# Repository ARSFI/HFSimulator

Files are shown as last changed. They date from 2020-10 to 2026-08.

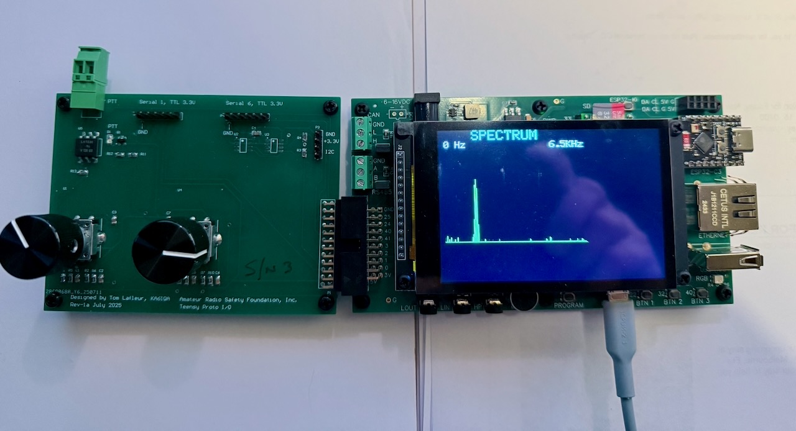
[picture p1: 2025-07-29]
hardware/Alternate hardware platforms/photos/IMG_5685.jpeg

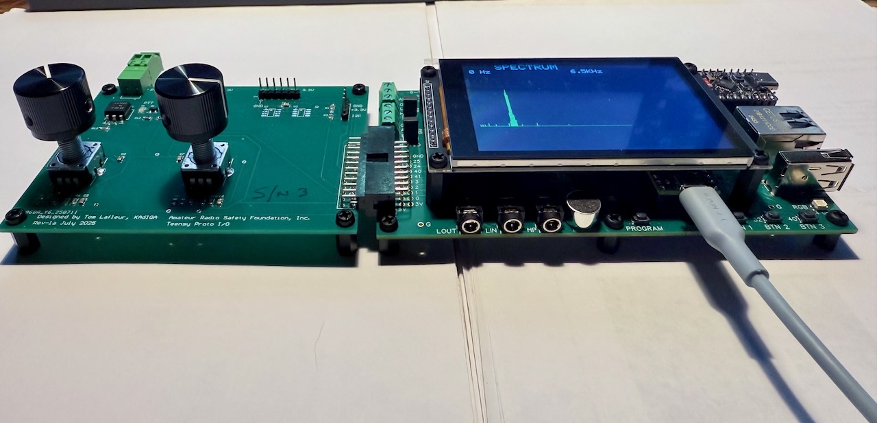
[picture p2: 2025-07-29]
hardware/Alternate hardware platforms/photos/IMG_5684.jpeg

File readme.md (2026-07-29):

<h2> A practical Open Source Ionospheric Channel Simulator</h2>                      

Rick Muething KN6KB, Tom Lafleur KA6IQA, Tom Whiteside N5TW

This project introduces a practical high-performance stand-alone and OS independent Ionospheric Channel
Simulator. Full open source documentation is available here.

A feature article with more detail is in the QEX March/April 2022.

The Amateur Radio Safety Foundation introduces the IONOS Channel Simulator, an audio-processing, 1-4 path (ray) simulator that models common HF and VHF/UHF propagation channels. It is intended to accelerate modem and protocol design, analysis, optimization and comparison, but has other uses as well. It allows off-air laboratory testing and evaluation of radio protocols and modems using statistically-standardized channel characteristics that would be almost impossible to achieve with over-the-air RF testing. Automation features allow scripting for multiple test runs under automatic control for huge time and labor savings. Since no transceivers are needed, the device may also be used as an inexpensive operator training station for exercising and teaching digital mode software. The simulator is based on the well-documented Watterson model [1] used by many laboratory grade instruments costing many thousands of dollars.

What is An Ionospheric Simulator?

Every ham learns that much of our communication relies heavily on radio wave propagation through the Ionosphere
layer. This layer reflects radio waves and can create single or multiple hop paths from station to station. While most
radio waves involve this type of propagation it is not trivial to model the constantly changing Ionosphere to test and
optimize the performance of our radios and protocols. On-air tests are notoriously unpredictable and difficult or
impossible to duplicate at another time.

In 1970 a landmark paper by Watterson, Juroshek, and Bensema was presented in the IEEE Transaction on
Communication Technology. They described a mathematical process (model) that could fairly accurately model and
simulate radio propagation over narrow band HF. This and follow-on papers by others and the CCIR/ITU defined a
set of standardized “representative test channels” that would allow computer software or hardware simulators to
statistically model HF radio propagation by manipulating the modulating audio. This has been used over the years to
develop, test, and improve many of the various digital and digital voice protocol we use today.

<h3> NOTE: Ver 2 and Ver 3 boards are identical, except that Ver 3 allows for socket pins for both Teensy 4.0 and 4.1. 
A Teensy 4.1 can be added to Ver 2 boards, but the extra pins are not in a socket. </h3>

<em><strong>Featured in the March/April 2022 issue of ARRL's QEX Magazine.

For alternate hardware update see:  

https://github.com/ARSFI/HFSimulator/tree/master/New%20alternate%20hardware%20platforms

A new small batch of IONOS development boards with a case are available from The Amateur Radio Safety Foundation, Due to the uncertainty regarding import tariffs and component costs, the final pricing for this batch has increased.

To buy assembled IONOS, blank PCB boards and cases, visit us at: https://shop.arsfi.org </a></strong></em>

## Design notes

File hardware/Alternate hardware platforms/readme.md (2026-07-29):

An alternative platform for users of this software..

Proto-supply has a development board using the Teensy 4.1, a 320x480 TFT display, with a SGTL5000 Codex.
https://protosupplies.com/product/mini-platform-teensy41/

All that is needed to run the IONOS code is a pair of encoders!,
just wire them to their I/O connector, 7 wires.
https://protosupplies.com/product/dual-rotary-encoder-module/

There is NO Audio buffering on the mini-platform, so audio in-out is connected directly to the SGTL5000 codex.

Or, we did an "encoder proto board" for another project that plugs directly into the mini-platform. 
As a minimum, you need only to install the two encoders, the 24 pin I/O connector and four jumpers.
The cost was less than $8 for 5 boards plus shipping from:
https://jlcpcb.com/

We have a version of code that runs on the board, with modification for the new TFT display.

Design documents for the "encoder proto board", including schematics, and Gerber files are available on this site.
Source code and binary HEX files for the updated TFT display are also available.

To use this board for IONOS, as a minimum, just install the two encoders, P1 and replace R5,R6,R9,R10 with jumpers.
Nothing else is needed...

If you build code from source, you will need Teensyduino version 1.60b4 or newer to support the ST7789 TFT display.

A .hex file is available to directly load into the Teensy.

https://github.com/ARSFI/HFSimulator/tree/master/New%20alternate%20hardware%20platforms/src/build/teensy.avr.teensy41

https://forum.pjrc.com/index.php?forums/announcements.6/

tom@lafleur.us ka6iqa

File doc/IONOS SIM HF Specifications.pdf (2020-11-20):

### IONOS SIM HF/VHF Channel Simulator Specifications

Rev Nov 17, 2020 (Firmware rev 2.03)

Description: IONOS SIM is a self-contained audio DSP based ionospheric simulator based on the Watterson Model [1] for ITU/CCIR standardized HF and VHF propagation paths. It uses the Teensy 4.0 CPU (ARM Cortex-M7 processor at 600 MHz) and Teensy Audio DSP Library.

Primary Use: The development, characterization, maintenance and comparison of HF and VHF modems and protocols including “sound card” protocols.

Channels Modeled: WGN (White Gaussian Noise: Spread 0 Hz, Delay: 0 ms); , MPG (CCIR Multipath Good) Spread .1 Hz, Delay .5 ms ; MPM (CCIR Multipath Moderate) Spread .5 Hz, Delay 1 ms; , MPP (CCIR Multipath Poor) Spread 1 Hz, Delay 2 ms; MPD (Multipath disturbed) Spread 2 Hz, Delay 4 ms; Flat Fading 0-40 dB, Fade Rate: .1-20 Hz; Fixed Freq offset +/- 200 Hz, 10 Hz steps; Slow FM deviation +/- 1-200 Hz, Rate .1 to 20 Hz; Multipath update rate 64x Doppler spread. Fade, offset, and FM can be combined with mode WGN.

Audio Paths: WGN: 1 path. Multipath: 2 or 4 I&Q paths. Input to Output Delay: Min 3.5ms (WGN); Max 8 ms (Multipath Disturbed). Multipath 2 paths: I2, Q2 Paths delayed by .5, 1, 2, or 4 ms.
Multipath 4 paths: 12,Q2 Paths delay by .25, .5, 1, or 2 ms I3,Q3 paths delayed by .5, 1, 2, or 4 ms.
I4,Q4 paths delayed by .75, .1.5, 3, or 6 ms

Connections Modeled: 1 Simulator: Half duplex, both sides, symmetric channel models. 2 Simulators: Full Duplex both sides: symmetric or asymmetric channel models.

Bandwidths: 3 KHz: 300 Hz to 3.3 KHz, 6 KHz: 300 Hz to 6.3 KHz. +/- 1dB Sampling rate: 44.1 KHz

Noise modeling: WGN filtered to 3 KHz or 6 KHz bandwidth. S:N -40 to +40 dB, 1 dB steps.

Inputs: Ch1, Ch2 via standard Stereo 1/8” (3.5 mm) jack. AC coupled. Input protection. Impedance > 50KOhms. Nominal input range: 10 – 1800 mv p-p. Manual input level control. Internal simulator level and input crest factor (CF) displayed.

Outputs: Ch1, Ch2 via standard Stereo 1/8” (3.5 mm) jack. AC Coupled. Short circuit protection. Impedance 150 Ohms. Nominal output range 10 - 1800 mv p-p. Manual output level control.

Power Required: Nominal 5 v (internally reg. to 3.3 V) via micro USB connector. < 200 ma.

Display: 320H x 240V pixel color TFT for Text and Graphics. (parameter settings, input level/CF, 3 & 6 KHz Spectrum Display)

Modes: Self-Test and Calibration verification to +/-1 dB Across operating BW; Setup modes and parameters;

User Parameter settings and control: Two Incremental encoders (Mode, Parameter) each with push toggle. Alternate USB serial ASCII commands for automated operation (4800-115200 baud).

Size: 6.1” (155 mm) L x 4.7” (120 mm) W x 1.4” (36 mm) H (excluding knobs).

Alternate Functions: Integrated Busy Channel Detector (experimental). Uses only serial USB ASCII command interface with host program.

[1] Watterson, C.C., J.R. Juroshek, & W.D. Bensema. 1970 Experimental confirmation of an HF channel model IEEE Transaction of Communication. Technology. Vol COM-18. Pp 792-803 Dec 1970

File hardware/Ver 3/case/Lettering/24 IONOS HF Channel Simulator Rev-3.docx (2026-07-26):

This is the text for the top and back panel…

Layout and fonts as in the photos is an example, and not firm. We hope your designer can use his/her design skills and provide suggestion of a cleaner layout. (number in from of text is font size, and is not firm)

22 IONOS HF/VHF Channel Simulator

Font is: Baskerville

12 Line-In Line-Out USB PTT

12 Rick Muething, KN6KB

12 Tom Lafleur, KA6IQA

12 Tom Whiteside, N5TW

12 Amateur Radio Safety Foundation Inc.

12 Mode Parameters

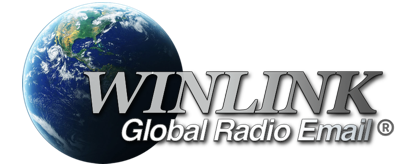
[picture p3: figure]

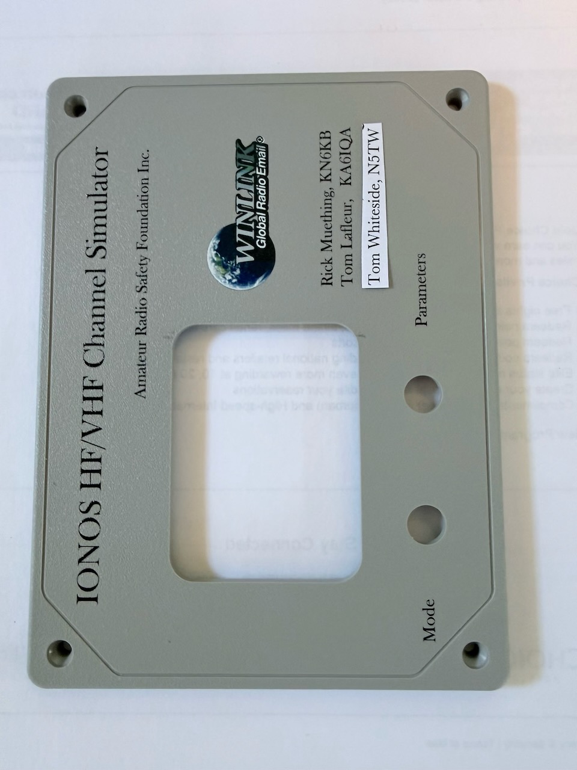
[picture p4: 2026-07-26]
hardware/Ver 3/case/Photo's/Updated Lid Artwork.jpeg

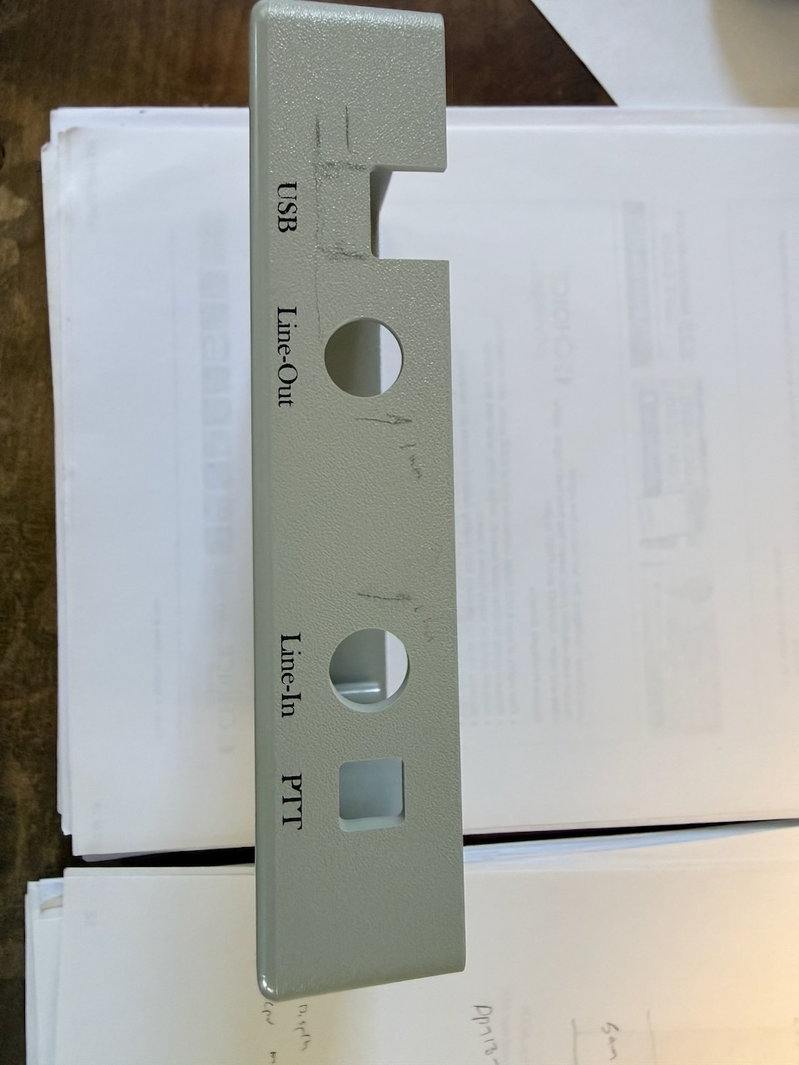
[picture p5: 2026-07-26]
hardware/Ver 3/case/PolyCase Ver-3/HF-Sim PolyCase V3/Rev-3/Photo's/Original Side Artwork.jpeg

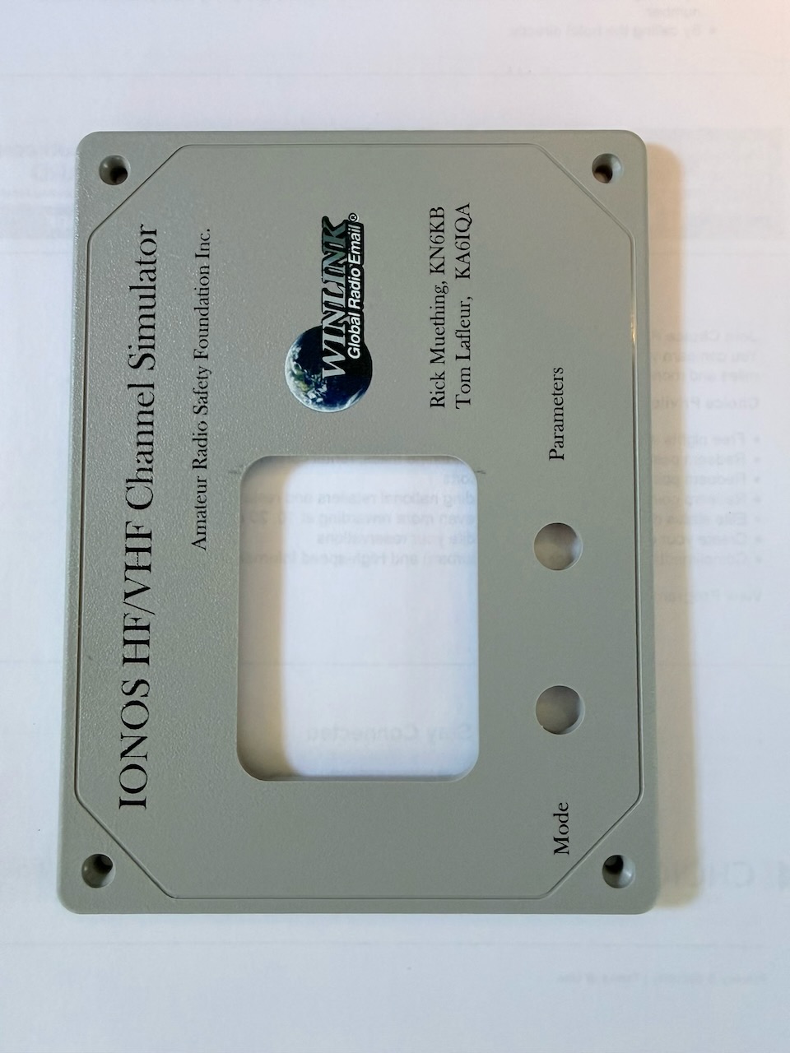
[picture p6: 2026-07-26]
hardware/Ver 3/case/Photo's/Original Lid Artwork.jpeg

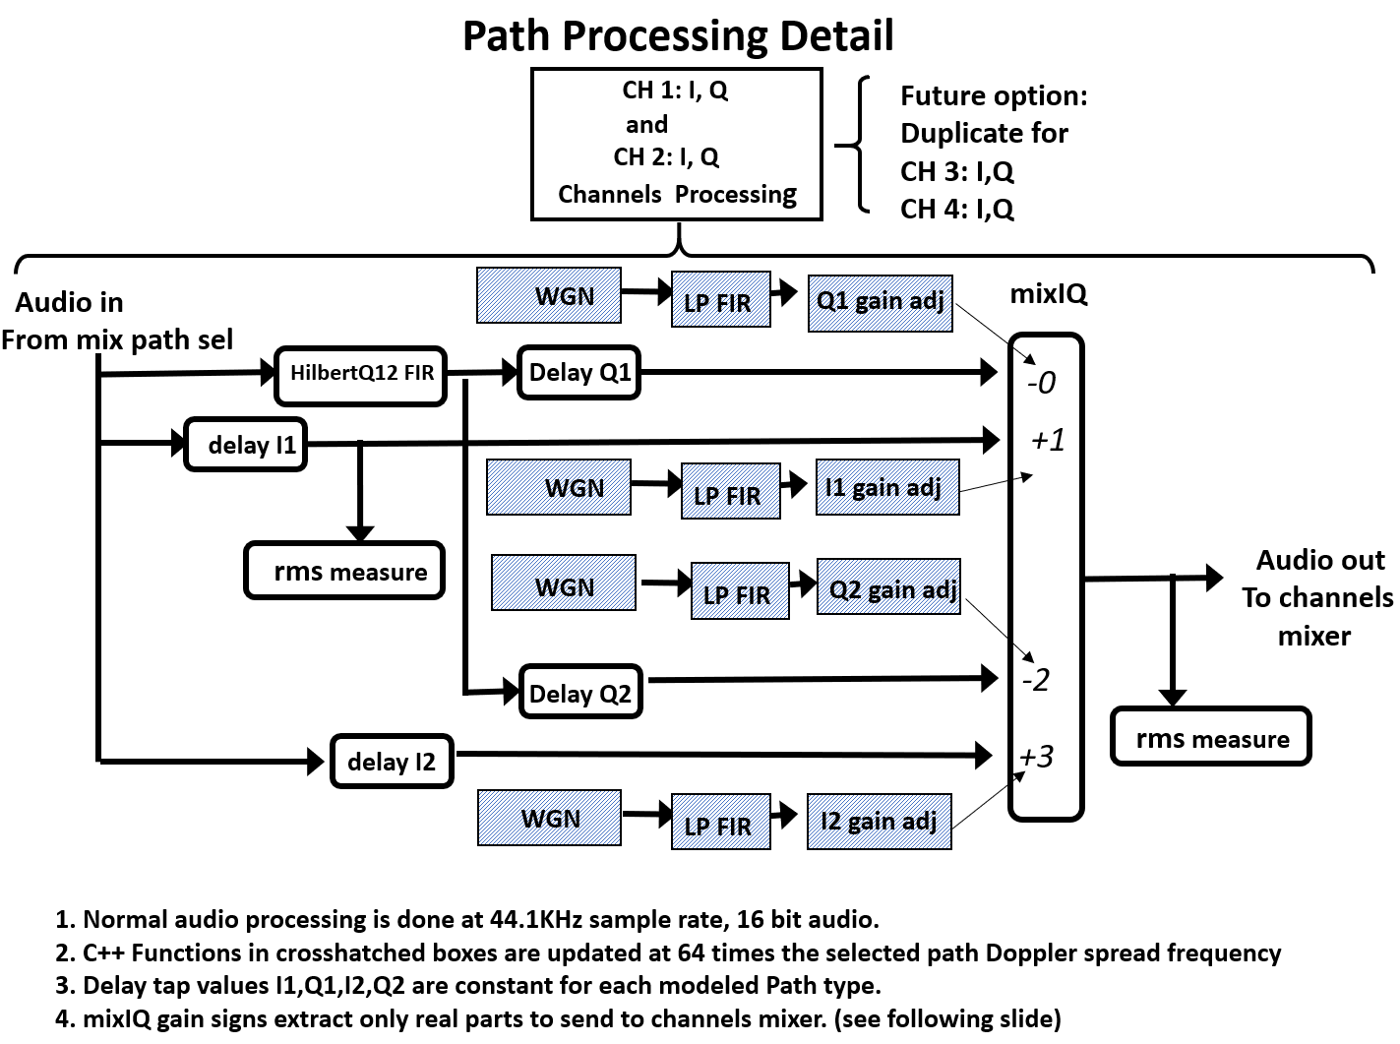
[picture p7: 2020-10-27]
doc/QEX/attachments/Fig 2. Path Processing Detail for two I & Q paths.png

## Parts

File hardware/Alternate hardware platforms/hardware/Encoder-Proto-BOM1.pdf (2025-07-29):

Designator | Comment | Part Number | Footprint | Qty | Cost | Total
C1, C2, C3,C5, C6, C7 | .01 uf/50v | | 0805 | 6 | $0.10 | $0.60
C4 | .1uf/50v | | 0805 | 1 | $0.10 | $0.10
R1,R2,R7,R8 | 4.7k | | 0805 | 4 | $0.10 | $0.40
R5,R6,R9,R10,R12 | 10k | | 0805 | 5 | $0.10 | $0.50
R3,R4 | 2.2k | | 0805 | 2 | $0.10 | $0.20
U1,U2 | Encoder | PEC11R-4225F-S0024 | | 2 | $1.78 | $3.56
R11 | 560 | | 0805 | 1 | $0.10 | $0.10
R13 | 22 Ohm | | 0805 | 1 | $0.10 | $0.10
D1 | LED Amber | LTST-C170KSKT | 0805 | 1 | $0.18 | $0.18
Q1 | FET | 2N7000BLK | SOT3 | 1 | $0.50 | $0.50
U5 | SS Switch | LH1500aab | | 1 | $2.29 | $2.29
P1 | 24 pin header | PPPC122LJBN-RC | | 1 | $1.32 | $1.32
P2,P3 | Header .1in 6 pin | | | 2 | $0.15 | $0.30
J1 | 2 Pin Jack, 5.08 | 2MA-02 | | 1 | $1.25 | $1.25
Knob | | | | 2 | $0.50 | $1.00
| | | | | | $0.00
| | | | | | $0.00
Total: | $12.40

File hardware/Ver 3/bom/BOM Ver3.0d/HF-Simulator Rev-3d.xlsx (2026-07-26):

Comment | Description | Designator | Footprint | LibRef | Quantity
.1uf | Capacitor | C1, C9, C10, C12, C13, C18, C26, C28 | 6-0805 | CAP_1 | 8
22uf | Capacitor | C2, C27, C29 | 0805 | CAP_1 | 3
.01uf | Capacitor | C3, C4, C5, C6, C7, C8 | 6-0805 | CAP_1 | 6
10uf | Capacitor | C11, C25 | 0805 | CAP_2 | 2
.15uf | Capacitor | C14 | 6-0805 | CAP_1 | 1
10uf | Capacitor | C15, C16, C17, C19, C20, C21, C22, C23, C24 | 6-0805 | CAP_1 | 9
LED-1 |  | D1 | LED 0805 | LTST150 | 1
LED-3 |  | D2 | LED 0805 | LTST150 | 1
PWR 3.3V |  | D3 | LED 0805 | LTST150 | 1
LED-2 |  | D4 | LED 0805 | LTST150 | 1
TS2A | Screw Terminal, 3.81mm (.15in) 2X | J1 | TS3.81X2 | TS2A | 1
SJ1-3533N | 3.5 mm phone jack | J2, J3 | CUI_SJ1-3533NG | SJ1-3533NG | 2
FB |  | L1 | 6-0805 | INDUCTOR | 1
I2C-Test | Header, 4-Pin | P1 | HDR1X4 | Header 4 | 1
LCD-Header 2.8in | Header, 14-Pin | P2 | HDR1X14 | Header 14 | 1
LCD-Header 2.2in | Header, 9-Pin | P3 | HDR1X9 | Header 9 | 1
LCD-Header | Header, 5-Pin | P4 | HDR1X5 | Header 5 | 1
IRLML6244TR | HEXFET N-Channel | Q1 | micro3 | IRLML6244TR | 1
1.2k | Precision Thick Film Chip Resistor, 10 Ohm to 2.2M Ohm Range, 1% Tolerance, 1206 Size, 0.125 W | R1, R2, R3, R4 | 6-0805 | ERJ8EN | 4
4.7k | Precision Thick Film Chip Resistor, 10 Ohm to 2.2M Ohm Range, 1% Tolerance, 1206 Size, 0.125 W | R5, R6 | 6-0805 | ERJ8EN | 2
10k | Precision Thick Film Chip Resistor, 10 Ohm to 2.2M Ohm Range, 1% Tolerance, 1206 Size, 0.125 W | R7, R8, R9, R10, R22, R29, R37, R40, R41 | 6-0805 | ERJ8EN | 9
120 | Precision Thick Film Chip Resistor, 10 Ohm to 2.2M Ohm Range, 1% Tolerance, 1206 Size, 0.125 W | R15, R16, R17, R18, R19, R20, R23, R30, R31 | 6-0805 | ERJ8EN | 9
0 Ohms | Precision Thick Film Chip Resistor, 10 Ohm to 2.2M Ohm Range, 1% Tolerance, 1206 Size, 0.125 W | R24, R32, R38, R39 | 6-0805 | ERJ8EN | 4
100k | Precision Thick Film Chip Resistor, 10 Ohm to 2.2M Ohm Range, 1% Tolerance, 1206 Size, 0.125 W | R25, R27, R28, R33, R35, R36 | 6-0805 | ERJ8EN | 6
1k | Precision Thick Film Chip Resistor, 10 Ohm to 2.2M Ohm Range, 1% Tolerance, 1206 Size, 0.125 W | R26, R34 | 6-0805 | ERJ8EN | 2
Teensy 4.1 |  | U1 | DIP48-.25pins | Teensy_4.1_SBC | 1
PEC11R-4015F-S0024 | Undefined or Miscellaneous | U2, U3 | PEC12R-4XXXF-SXXXX_1 | PEC11R-4015F-S0024 | 2
AP7313-18SRG-7 | Integrated Circuit | U4 | SOT96P240X135-3N | AP7313-30SRG-7 | 1
SGTL5000XNAA3 | Integrated Circuit | U5 | QFN50P500X500X90-33N | SGTL5000XNAA3 | 1
PVT312 | SS Relay, 250V 200ma | U6 | SOP254P978X342-6N | PVT312 | 1
OPA2322AID | 20 MHz, Low Noise, RRIO, CMOS Operational Amplifier, 1.8 to 5.5 V, -40 to 125 degC, 8-pin SOIC (D8), Green (RoHS & no Sb/Br) | U7 | D0008A_L | CMP-0271-00129-3 | 1

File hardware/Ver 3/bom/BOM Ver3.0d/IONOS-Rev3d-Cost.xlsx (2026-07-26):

Date | Vendor | Part | Tariff | Shipping | Cost | Tax | Total
2026-03-12 | JCLPCB | Parts deposit |  |  | 5.86 |  | 5.86
2026-03-17 | JCLPCB | SGTL5000 Part order |  |  | 97.48 |  | 97.48
2026-03-16 | Mouser | Connector ESW-114-23-L-S |  | 8.49 | 56.32 |  | 64.81
2026-03-11 | PolyCase | Cases |  | 24.46 | 957.10 |  | 981.56 | 39.26 | 25 cases
2026-03-17 | JCLPCB | Parts deposit, Refund |  |  | -5.86 |  | -5.86
2026-03-17 | JCLPCB | PCB + Assembly + Parts | 155.64 | 114.95 | 453.68 | 3.04 | 727.31 | 48.49 | 15 each, 25 boards
2026-03-18 | Sparkfun | Teensy 4.1 |  |  | 651.67 |  | 651.67 | 36.20 | 3 extra
2026-03-18 | Mouser | Connectors for Teensy |  |  | 70.58 |  | 70.58 |  | 10 extra
2026-04-10 | Ebay | Display | 48.75 |  | 194.81 |  | 243.56 |  | 3 extra units
 | Mouser | Knobs |  |  | 150.00 |  | 150.00 |  | Stock ok
 |  |  |  |  |  |  | 0.00
 |  |  |  |  |  |  | 0.00
 |  |  |  |  |  |  | 0.00
 |  |  |  |  |  |  | 0.00
 |  |  |  |  |  |  | 0.00
 |  |  |  |  |  |  | 0.00
 |  |  |  |  |  |  | 0.00
 |  |  |  |  |  |  | 0.00
 |  |  |  |  |  |  | 0.00
 |  |  |  |  |  | Total: | $2986.97
 |  |  |  |  |  | 15 | $199.13 |  | <--- Est Cost Per unit`

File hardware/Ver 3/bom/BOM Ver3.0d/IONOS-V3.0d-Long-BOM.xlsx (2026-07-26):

Name | Description | Designator | Notes | Package | Quantity | Manufacturer | Manufacturer Part Number | JLCPCB Part Number | Alt Part | Cost | Total Cost
.1uf/50v | Capacitor, 50v, 0805 | C1, C9, C10, C12, C13, C18, C26, C28 |  | 0805 | 8 | Samsung | CL21B104KBCNNNC | C1711 |  | 0.0033 | 0.0264
22uf/10V | Capacitor, 10v, 0805 | C2, C27, C29 |  | 0805 | 3 | Samsung | CL21A226MAQNNNE | C45783 |  | 0.0189 | 0.0567
.01uf | Capacitor | C3, C4, C5, C6, C7, C8 |  | 0805 | 6 | Samsung | CL21B103KBCNNNC | C5137493 |  | 0.0131 | 0.0786
10uf/10v | Capacitor, 10v, 0805 | C11, C25, C15, C16, C17, C20, C21, C22, C23 |  | 0805 | 9 | Samsung | CL21A106KAYNNNE | C15850 |  | 0.0119 | 0.1071
10uf/10v | Capacitor, 10v, 0805 | C19, C24 | Not Installed | 0805 | 0 | Samsung | CL21A106KAYNNNE | C15850 |  | 0.0119 | 0.0000
.15uf/50v | Capacitor, 50v, 0805 | C14 |  | 0805 | 1
 |  |  |  |  |  |  |  |  |  |  | 0.0000
1.2k | Resistor - 0805 1% - Metal Film | R1, R2, R3, R4 |  | 0805 | 4 | Yageo | RC0805FR-071K2L | C114526 |  | 0.0023 | 0.0092
4.7k | Resistor - 0805 1% - Metal Film | R5, R6 |  | 0805 | 2 | Yageo | RC0805FR-074K7L | C60816 |  | 0.0023 | 0.0046
10k | Resistor - 0805 1% - Metal Film | R29, R37, R22 | Not Installed | 0805 | 0 | Yageo | RC0805FR-0710KL | C84376 |  | 0.0023 | 0.0000
10k | Resistor - 0805 1% - Metal Film | R7, R8, R9, R10, R40, R41 |  | 0805 | 6 | Yageo | RC0805FR-0710KL | C84376 |  | 0.0023 | 0.0138
120 | Resistor - 0805 1% - Metal Film | R23 | Not Installed | 0805 | 0 | Yageo | RC0805FR-07120RL | C114245 |  | 0.0023 | 0.0000
120 | Resistor - 0805 1% - Metal Film | R15, R16, R17, R18, R19, R20, R30, R31 |  | 0805 | 8 | Yageo | RC0805FR-07120RL | C114245 |  | 0.0023 | 0.0184
0 Ohms | Resistor - 0805 1% - Metal Film | R38 | Not Installed | 0805 | 0 | Yageo | RC0805FR-070RL | C5196743 |  | 0.0023 | 0.0000
0 Ohms | Resistor - 0805 1% - Metal Film | R24, R32, R39 |  | 0805 | 3 | Yageo | RC0805FR-070RL | C5196743 |  | 0.0023 | 0.0069
100k | Resistor - 0805 1% - Metal Film | R25, R27, R28, R33, R35, R36 |  | 0805 | 6 | Yageo | RC0805FR-07100KL | C96346 |  | 0.0023 | 0.0138
1k | Resistor - 0805 1% - Metal Film | R26, R34 |  | 0805 | 2 | Yageo | RC0805FR-071KL | C95781 |  | 0.0023 | 0.0046
 |  |  |  |  |  |  |  |  |  |  | 0.0000
Socket | 48Pin (4 each 12pin headers) | U1 | Not Installed | 2.54mm header | 4 | FCI | 76341-312LF |  |  | 1.2200 | 4.8800
Teensy 4.0 | Teensy_4.0_SBC | U1 | Not Installed | DIP28-.25pins | 0 | Sparkfun | DEV-16997 |  |  | 26.8000 | 0.0000
Teensy 4.1 | Teensy_4.1_SBC | U1 | Not Installed | DIP48-.25pins | 1 | Sparkfun | DEV-20360 |  |  | 33.6000 | 33.6000
OPA2322AID | 20 MHz, Low Noise, RRIO, CMOS Operational Amplifier, 1.8 to 5.5 V, -40 to 125 degC, 8-pin SOIC (D8), Green (RoHS & no Sb/Br) | U7 |  | SOP-8 | 1 | Texas Instruments | OPA2322AID | C2058012 |  | 0.0669 | 0.0669
AP7313-18SG-7 | LDO, 1.8v | U4 |  | SOT-23-5 | 1 | Diode Inc | AP7313-18SG-7 | C460373 | C150747 | 0.0644 | 0.0644
SGTL5000XNBA3 | Audio Codec | U5 |  | QFN 32 | 1 | NXP | SGTL5000XNBA3 | C5196742 |  | 7.1100 | 7.1100
LH1500AAB | SS Relay, 250V 200ma | U6 | Not Installed | SMD DIP-6 | 0 | Visahy | LH1500AAB | C3008868 |  | 2.0169 | 0.0000
IRLML6244TR | HEXFET N-Channel | Q1 | Not Installed | SOT-23-3 | 0 |  |  |  |  |  | 0.0000
 |  |  |  |  |  |  |  |  |  |  | 0.0000
PEC11R-4030F-S0024 | Shaft Encoder with switch | U2, U3 |  | Special | 2 | Bourns | PEC11R-4030F-S0024 | C7435302 |  | 2.1000 | 4.2000
SJ1-3533N | 3.5 mm phone jack | J2, J3 |  | Special | 2 | CUI | SJ1-3533N | C4992360 | C4992359 | 1.1200 | 2.2400
 |  |  |  |  |  |  |  |  |  |  | 0.0000
1k @ 100 Mhz | Ferrite Bead 1k @ 100 Mhz | L1 |  | 0805 | 1 | TDK | MPZ2012S102ATD25 | C80983 |  | 0.0400 | 0.0400
 |  |  |  |  |  |  |  |  |  |  | 0.0000
PWR 3.3V |  |  | Not Installed | 0805 | 0 |  |  |  |  |  | 0.0000
LED-1 |  |  | Not Installed | 0805 | 0 |  |  |  |  |  | 0.0000
LED-2 |  |  | Not Installed | 0805 | 0 |  |  |  |  |  | 0.0000
LED-3 |  |  | Not Installed | 0805 | 0 |  |  |  |  |  | 0.0000
 |  |  |  |  |  |  |  |  |  |  | 0.0000
 |  |  |  |  |  |  |  |  |  |  | 0.0000
TS2A |  |  | Not Installed |  | 0 |  |  |  |  |  | 0.0000
I2C-Test | Header, 4-Pin | P1 | Not Installed | 2.54mm header | 0 | Samtec | ESW-104-23-L-S |  |  |  | 0.0000
LCD-Header 2.8in | Header, 14-Pin | P2 |  | 2.54mm header | 1 | Samtec | ESW-114-23-L-S | C21220402 |  | 3.7730 | 3.7730
LCD-Header 2.2in | Header, 9-Pin | P3 | Not Installed | 2.54mm header | 0 | Samtec | ESW-109-23-L-S | C22332317 |  |  | 0.0000
LCD-Header | Header, 5-Pin | P4 |  | 2.54mm header | 1 | Samtec | ESW-105-23-L-S | C3320536 |  | 0.0710 | 0.0710
 |  |  |  |  |  |  |  |  |  |  | 0.0000
LCD-Display | 2.8in TFT SPI 240x320 v1.1, ILI9341 |  |  |  | 1 |  | TJCTM204028SPI |  |  | 12.0000 | 12.0000
Knobs |  |  |  |  | 2 |  |  |  |  | 5.0000 | 10.0000
Case |  |  |  |  | 1 |  |  |  |  | 38.5000 | 38.5000
 |  |  |  |  |  |  |  |  |  |  | 0.0000
 |  |  |  |  |  |  |  |  | Total Parts Cost: |  | 116.8854

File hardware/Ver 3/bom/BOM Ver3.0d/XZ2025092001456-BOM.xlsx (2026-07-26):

Designator | Footprint | Quantity | Comment | LCSC## | Note
C1, C2, C3, C5, C6, C7, C8 | 0805 | 7 | CL21A106KAYNNNE | C15850
C4, C9, C12, C13, C15, C19, C20, C21, C22, C23, C24, C25, C26, C27, C28, C29, C30 | 0805 | 17 | CL21B104KBCNNNC | C1711
C10, C11, C16, C18 | 0805 | 4 | CL21A226MAQNNNE | C45783
C14, C33, C34 | 0805 | 3 | C2012X5R1A476MTJ00E | C76636
C31 | 0805 | 1 | CC0805KRX7R9BB154 | C107144
D1 | 0805 | 1 | LTST-C170KRKT | C94868
J1, J2, J5 | Special | 3 | SJ1-3533N | C4992360 | Empty post
J4 | Special | 1 | KMDGX-6S-BS | C5445019 | Empty post
J6 | Special | 1 | KMDGX-8S-BS | C5780060 | Empty post
J7 | Special | 1 |  | C131339
L1 | 0805 | 1 | MLZ2012N101LT000 | C88184
Q1 | SOT-23-5 | 1 | AO3414 | C48850
R1, R4, R9, R12 | 0805 | 4 | 100k | C96346
R2, R10 | 0805 | 2 | 1k | C95781
R3, R11, R30, R31, R21, R28, R29 | 0805 | 7 | 10k | C84376
R5, R6 | 0805 | 2 | 120 | C114245
R7, R8 | 0805 | 2 | 330k | C114528
R17 | 0805 | 1 | 0 Ohm | C100045
R18 | 0805 | 1 | 4.7k | C60816
R20 | 0805 | 1 | 62 | C228941
R22 | 0805 | 1 | 560 | C114536
R23, R24, R25, R26, R27 | 0805 | 5 | 100 | C105577
U1 | SOP-8 | 1 | OPA2322AID | C2058012
IC3 | SOT-23-5 | 1 | AP7313-18SG-7 | C460373
U4 | TSSOP-16 | 1 | MAX3221ECPWR | C350553
U5, U10 | SOT-23-5 | 2 | SN74LVC1G86DBVT | C402161 | Note: Replacement Material
U6 | SOT-23-5 | 1 | SN74LVC1G07DBVT | C2867373
U7, U9 | SOT-23-5 | 2 | SN74LVC1G125DBVT | C7834 | Note: Replacement Material
U8 | SOT-23-5 | 1 | SN74LVC1G126DBVT | C7834
U12 | SMD DIP-6 | 1 | LH1500AAB | C3008868
U13 | QFN 32 | 1 | SGTL5000XNBA3/R2 | C5196743
Y1 | SMD 5 mm x 3.2 mm | 1 | ASFL1-12.288MHZ-EC-T | C276419

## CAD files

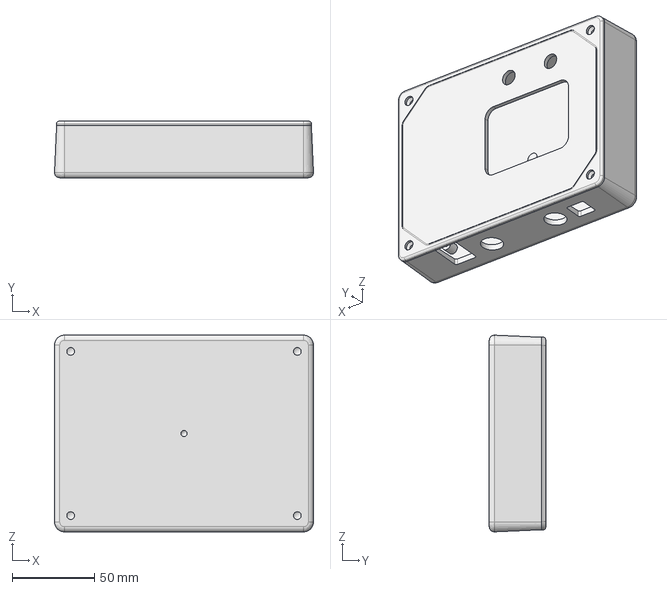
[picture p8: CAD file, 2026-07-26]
hardware/Ver 3/case/Drawings/DC-45PMBYT_Box_Rev3.step
157.8 x 34.5 x 119.9 mm
DC-46C_DC-46C-T
DC-45B_DC-45BPMBY

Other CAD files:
hardware/Ver 3/case/PolyCase Ver-3/HF-Sim PolyCase V3/Rev-1/14531129045667026 (2)/DC-45PMBYT_ASS'Y.STEP
hardware/Ver 3/case/PolyCase Ver-3/HF-Sim PolyCase V3/Rev-1/Lafleur_DC-45PMBYT_ASS'Y v7.step
hardware/Ver 3/case/PolyCase Ver-3/HF-Sim PolyCase V3/Rev-2/DC-45PMBYT_ASS'Y_BOX_Model v1.step
hardware/Ver 3/case/PolyCase Ver-3/HF-Sim PolyCase V3/Rev-2/remybox/DC-45PMBYT_ASS'Y_BOX_Model v1.step
hardware/Ver 3/case/PolyCase Ver-3/HF-Sim PolyCase V3/Rev-1/14531129045667026 (2)/DC-45PMBYR_ASS'Y.STEP

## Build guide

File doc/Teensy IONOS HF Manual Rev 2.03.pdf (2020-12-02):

## IONOS HF/VHF-UHF Channel Simulator

(with experimental BUSY DETECT Busy Channel Detection)
[Instructions, Basic Documentation, Specifications and Open Source Info]

Ref: Software Release revision 2.03 Rick Muething, KN6KB Nov 25, 2020

1.0 Introduction: The Teensy IONOS is an audio processing 1, 2, or 4 path simulator that models standard HF and VHF/UHF propagation channels. It is intended primarily for modem and protocol design, analysis, optimization and comparison. It allows non-radio testing of protocols and modems using statistically standardized channels that would be almost impossible to achieve with normal “over the air” RF testing. The simulator is based on the well-documented Watterson model [ 1] used by many laboratory grade instruments costing many thousands of dollars.

2.0 Basic Description: The IONOS Simulator is implemented using the low-cost but powerful Teensy 4.0 processor (https://www.pjrc.com/store/teensy40.html) and was developed using the Arduino platform and makes extensive use of the Teensy Audio DSP library https://www.pjrc.com/teensy/gui/index.html . The IONOS software is released under the MIT Open Source License (see appendix). Simplified and detailed block diagrams of the simulator are shown below in Fig 1 and Fig 2. The implementation uses 37 Teensy Audio Library “components” with 44 virtual “connections”. Fig 3 shows the detailed implementation of the I and Q path processing.

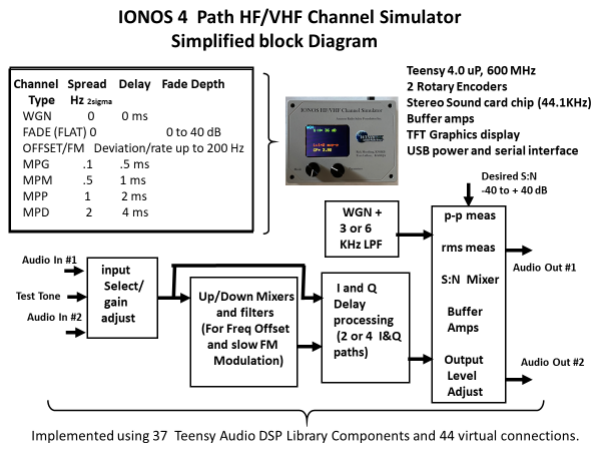
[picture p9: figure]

Fig 1. IONOS Sim 4 Path HF/VHF/UHF Channel Simulator Simplified Block Diagram

[1] Watterson, C.C., J.R. Juroshek, & W.D. Bensema. 1970 Experimental confirmation of an HF channel model IEEE Transaction of Communication. Technology. Vol COM-18. Pp 792-803 Dec 1970

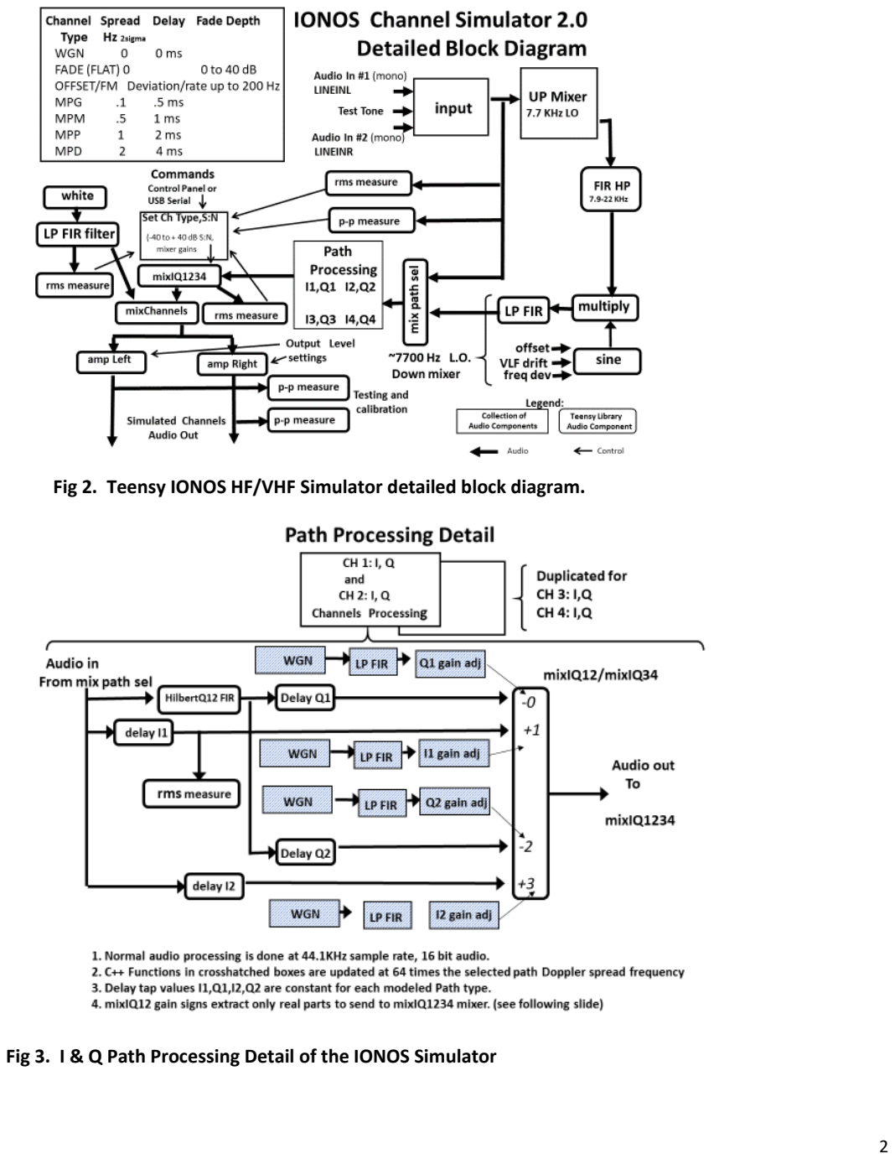
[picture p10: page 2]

Fig 2. Teensy IONOS HF/VHF Simulator detailed block diagram.

Fig 3. I & Q Path Processing Detail of the IONOS Simulator

3.0 Basic Layout: The Basic layout of the simulator circuit board is shown in Figs 4 & 5. The simplified user interface consists of just 2 rotary encoders (each with push action switch) and a small color graphics TFT display mounted in an ~ 4” x 6” customized PolyCase enclosure. Additional surface mount components are on the rear side of the PCB. The simulator is powered through its micro USB connector which also provides optional USB serial I/O for computer- controlled operation if desired. Audio input (2 mono channels) and audio output (2 mono channels) connections are made using standard 1/8” (3.5 mm) stereo phone jacks.

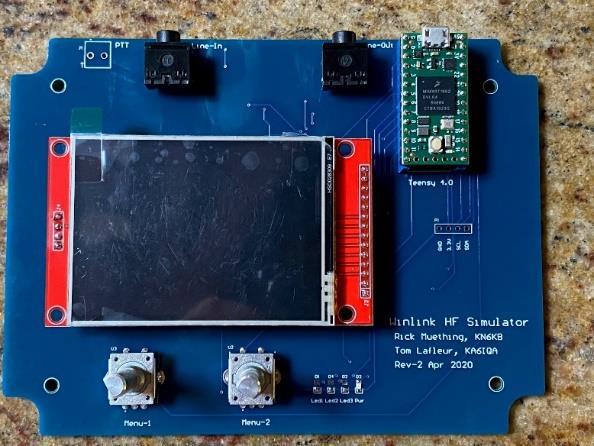
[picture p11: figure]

Fig 4. Basic control/display layout (Rev 2 prototype) Schematic, PCB design, layout assembly and test by Tom Lafleur KA6IQA

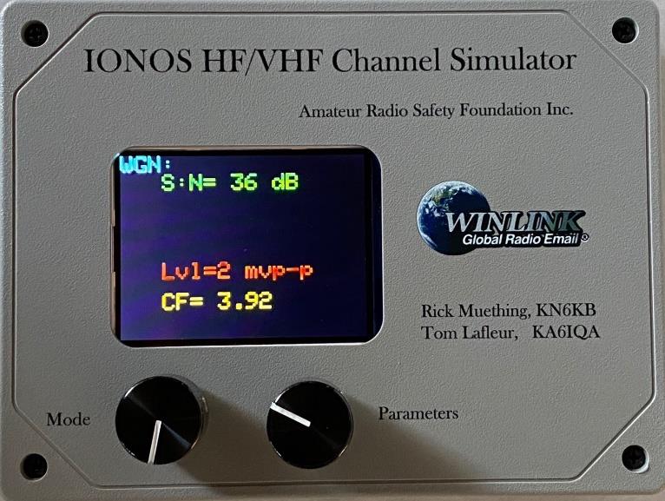
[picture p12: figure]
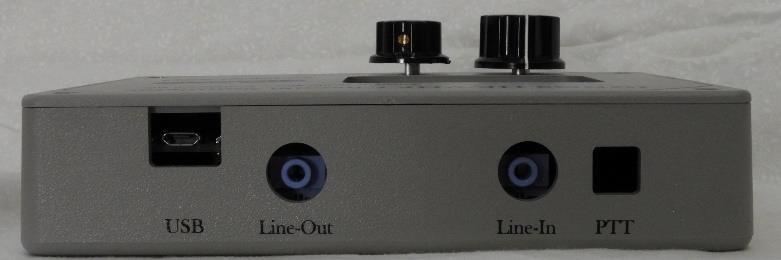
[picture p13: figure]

Fig 5. Production Front Panel and side connections

3.1 Automated Self-Test. There is a built-in mechanism for automated self-test and calibration verification. First connect the output jack to the input jack with a standard Stereo 1/8” (3.5 mm) 3 conductor male patch cord. This jumps the CH1 and CH2 output amplifiers to the CH1 and CH2 input buffers. The self-test software will block the normal in-to-out connection to avoid oscillations and accurately measure the levels of the precision internally generated test signal and the injection of the outputs for that signal back into the inputs. This verifies: a) Connections and wiring to the output and input jacks, b) proper amplifier resistor values/tolerance, c) proper low frequency coupling capacitors, d) Teensy Audio processing and DSP FIR filtering, e) Frequency response on both 3KHz and 6KHz bandwidths (Flat +/- 1dB). The self-test is also useful in setting up initial modem output levels.

3.1.1 Running the Self-Test. With the patch jumper above in place, power on the IONOS Simulator by plugging in the USB port. The software and self-test software are already loaded. After the power on display of the current code revision (e.g. IONOS SIM Rev 2.03 etc.) and serial number the display will enter the normal power on mode (WGN mode with S:N = 40 dB). Rotate the Mode (left hand encoder) knob 17 clicks CW to activate the TEST3K Sine: self-test. This will set up a 1500 Hz test sine wave at a specific amplitude and begin averaging the p-p (peak to peak) voltage readings at the input buffers (Ch1 in, Ch2 in) and output Amps (Ch1 Out, Ch2 Out). Averaging is used to increase resolution and after about 5 seconds the average measurements should stabilize to stable values (all values in p-p mv). If the values displayed are all green text, the measurements are with +/-1 dB of the specification …the basic accuracy of the simulator. Any values in red text are outside the +/- 1 dB limit above. Different levels for Ch1 and Ch2 are used to verify there is no cross-coupling. The entire range of frequencies for the 3 KHz bandwidth can be tested by rotating the right hand (parameter) knob. Frequency range for the TEST3K will range from 300 Hz to 3300 Hz. During the test you can toggle to the Spectrum display by pushing down on the Mode (left hand) encoder. Pushing again will toggle back to the TEST3K display. In a similar way rotating the mode knob CW one additional click (18 clicks from Power on WGN position) will enable the TEST6K test. It works exactly the same as the TEST3K but the frequency range spans 300 Hz to 6300 Hz. It exercises different FIR filters used in the 6 KHz bandwidth mode. Again, you may have to wait a few seconds for reading averages to stabilize. The 6 KHz mode swaps the Ch1/Ch2 amplitudes from the 3 KHz test insuring all paths are independent and work at full amplitude.

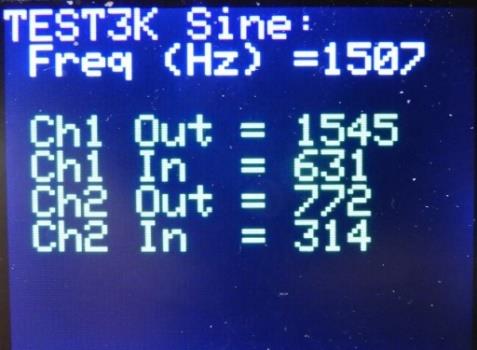
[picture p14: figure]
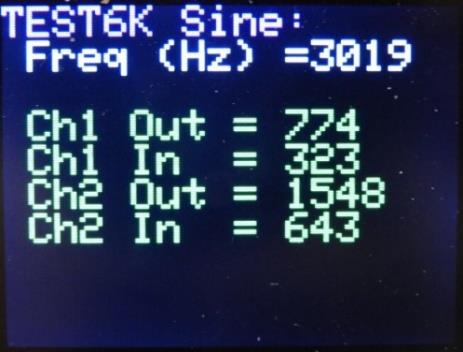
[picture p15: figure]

Fig 6. Example Screens for TEST3K an TEST6K self-test and calibration verification.

Green text indicates parameter within +/- 1 dB and values can vary from those shown above.

3.2 Getting Familiar with the controls and displays of IONOS SIM. You can gain familiarity with the simulator without hooking it up to any modems or TNCs. An earphone (mono or stereo) plugged into the Ch1,2 output jack will be helpful. Upon power-up after plugging in to a +5 v powered micro USB port the TFT display will Activate and show IONOS SIM version xxxxx for four seconds along with an 8 digit hex serial number before going to the Basic Mode display. There it will show the current mode “WGN:” in blue text and the current parameter value for that mode which will be “S:N= 40 dB” in green text. Also shown in the WGN mode is the internal signal level (mv p-p) and the Crest Factor (CR) of the input. WGN (White Gaussian Noise) is the most basic mode and one that will be used often for setup and initial testing runs. Rotate the right hand encoder (parameter) CW or CCW to roll through the S:N options (-40 to +40 dB). The display of mode settings/parameters and text colors are similar for the 14 other modes shown in Fig 8. (The self-test modes TEST3K and TEST6K are shown in magenta to distinguish them from normal operating modes) Most modes and settings can be left at their power on defaults for basic testing. For modes WGN-MPD pushing down on the right encoder until it clicks will toggle the internal 1500 Hz test tone on/off. You should hear the tone in the earphone and see the simulator’s internal p-p level in mv shown on the screen. Adjusting the S:N lower should increase the noise. Most people can still hear the signal down to about -10 to -15 dB below the noise (all dB measurements and calculation are based on the operational bandwidth (3000/6000 Hz). In other modes pushing down on the right encoder will save the current mode parameter to EEPROM as the power on default value. For modes WGN-MPD pushing on the left encoder knob should switch the display to the Spectrum mode (3.5 or 6.5 KHz). There you should see the test tone and the background noise (white noise filtered to bandwidth) displayed. The vertical plotting scale of the spectrum analyzer is logarithmic and covers approx. 60 dB dynamic range. Each spectrum line (2 pixels wide for 0 to 3500 Hz) represents one ~43 Hz frequency bin. Toggle off the spectrum display with another push of the mode knob) to return to the Basic Mode display. Now select a multipath mode (say MPD for Multi Path Disturbed). Push the Mode (left) encoder once to switch back to the spectrum display. There you will see the impact the multipath delays created by the simulator has on the 1500 Hz test tone. The amplitude fluctuations will be obvious but the small frequency deviations will not be visible on the spectrum display. MPD is a very poor

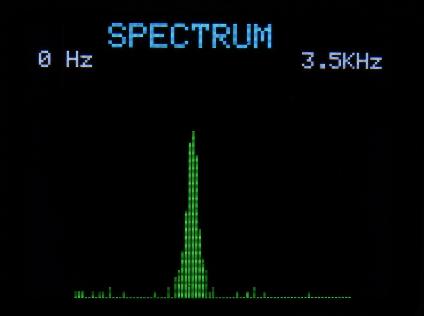
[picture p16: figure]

channel and HF digital communications on this path are often difficult or impossible.

Pushing the mode (left) encoder once more should return you to the Basic Mode display. For most parameters (except S:N on WGN-MPD) you can push the parameter (right) knob to set the displayed value as the power on default (stored in EEPROM). You can explore the various other mode and parameter settings. There are no settings that will damage the Simulator but care should be taken when advancing the output volumes (CH1, CH2 OUT) levels which could result in loud levels to some earphones.

3.3 Exploring the other modes and parameters for other testing. While the Multipath channels are primarily used in HF Path simulation the simulator also supports functions useful in VHF/UHF path simulation. This testing is usually done using the standard WGN channel (across a range of S: N range of interest) modified with functions for VHF/UHF simulation. The primary ones of these are FLAT fade caused by multipath signal reception on FM and FM Deviation caused by transmitter/receiver drift or doppler shift. Figure 9 shows these modes and the parameter range of each. Again the 1500 Hz test tone can be used as a basic signal source and the Spectrum analyzer display to observe these effects just as was done in the basic HF modes. The fixed OFFSET mode can also be used to supply a small (+/- 200 Hz range) frequency offset to the audio input and this is helpful in testing/evaluating the ability of the modem to handle frequency tuning offsets primarily on HF SSB transmission. These additional modes and parameters can be used with (applied to) the normal WGN channel. Note: OFFSET and FM Deviation cannot be used with multipath modes (MPG, MPM, MPP, MPD) due to the required precision necessary for proper multipath generation. If OFFSET or FM Deviation is enabled a yellow warning message “no FM or Offset!” will be displayed on the Multipath modes and the offset and/or FM Deviation will be ignored.

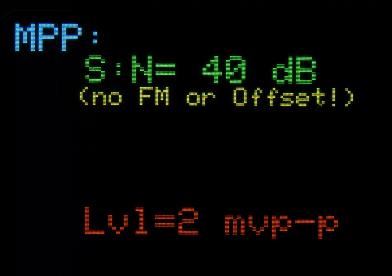
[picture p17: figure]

The simulator also supports a 6 KHz bandwidth mode. This can sometimes be useful for modeling wide band audio channels but is not normally used on amateur HF transmissions. The 6 KHz mode can be used in modeling wider band audio channels used on VHF and UHF such as 9600 baud packet or VARA VHF. In 6 KHz bandwidth mode the simulator’s internal FIR filters are all switched to a 6300 Hz range and the Spectrum display is modified to cover the full range 0 to 6500 Hz. In the 6500 Hz spectrum mode each ~43 Hz bin is represented by a one-pixel-wide vertical rectangle spaced by 1 pixel of black.

3.4 Internal Signal Levels and Crest Factor. The simulator also provides a continuous display of its peak internal signal level (mv p-p) in display modes WGN through MPD. This is designed to aid in setting Simulator output levels (CH1, CH2 OUT) and Simulator Input gain (CH1, CH2 IN) to appropriate operating levels. The full useable internal signal range of the simulator is 0 to 2000 mv p-p but normally signal levels should target an internal range of 200 to 1200 mv p-p (“Lvl=” reading) to accommodate fading and peaking in multipath modeling. The p-p and rms levels are measured at the output of the Input Low Pass filter and will display green when between 200-1200 mv p-p. There is also an internal level monitor at the output of the mixIQ1234 mixer and any level of the mixIQ1234 mixer > 1800 mv p-p will also trip the level monitor to red. This could be possible in some multipath cases and if observed the input level to the simulator or the CH1/CH2 IN gains should be reduced. The important goal is to not allow the internal peak audio level to get above 1200 mv to eliminate any chance of audio signal clipping internal to the simulator. Also, on all channel types the Crest Factor (CF) of the input waveform is computed and displayed every 200 ms if the Lvl is > 50 mv. To follow RF power metrology conventions the CF indicates the ratio of PEP (Peak Envelope Power) to Average Power. For reference a pure sine wave has an RF CF = 1.00 or 0 dB. The crest factor is useful when computing the energy per bit (Eb) in digital communications. Many SSB transmitters may not be able to sustain a CF below 2.0 (3dB) at max rated PEP for long periods (high duty cycles) due to thermal limitations so would require a reduced drive level to a lower PEP value.

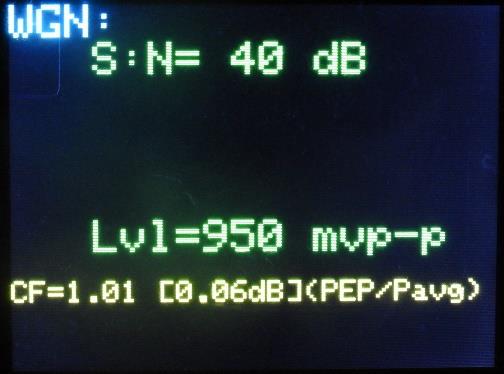
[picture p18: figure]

3.5 Adjusting for Protocol Bandwidth. The simulator supports two bandwidth options 3 KHz and 6 KHz and adjusts the S:N ratio based on the requested S:N setting and these bandwidths. This can work fine for comparing protocols of similar bandwidth but will result in some S:N calibration offset if the protocols are not 3KHz or 6KHz bandwidth. E.g. A VARA HF mode of 500 Hz bandwidth is actually operating at a S:N ratio of 10 * Log(3000/500) or ~7.8dB higher than the simulator setting for S:N used on the simulator set for 3000Hz bandwidth. If protocols of different bandwidths are plotted on the same graph their plotted S:N ratio should be adjusted for the actual bandwidth of the protocol. If the bandwidths are reasonably close (within 10-15%) the correction needed would be small (<.6 dB). This kind of bandwidth S:N adjustment is important when comparing very low bandwidth modes (PSK31, JT modes etc.) against other wider modes .

4.0 Basic Setup and Connections for using the Simulator. The simulator can be used to model the paths for non ARQ (one direction) or ARQ half-duplex or full duplex connections. With its’ internal audio CH1 and CH2 mixing a single IONOS SIM can handle both directions of a half-duplex ARQ connection providing symmetric channel modeling (same channel model for Modem 1 to Modem 2 and Modem 2 to Modem 1). Figs. 7 and 8 show the connections for both half duplex and full duplex channel modeling.

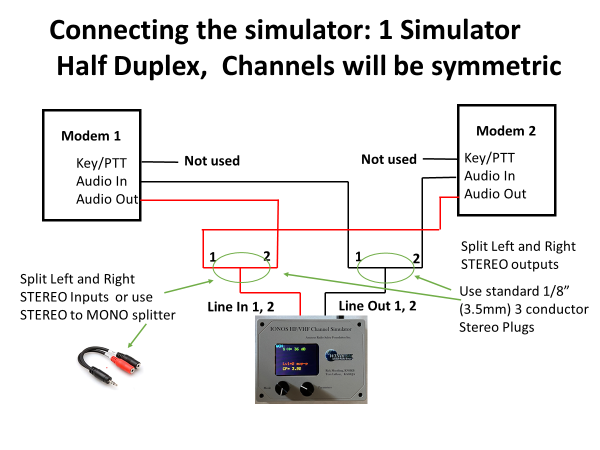
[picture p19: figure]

Fig 7. Basic Half Duplex, symmetric channel setup with one IONOS SIM.

(note: Stereo isolation transformers can be used if ground loops affect audio quality)

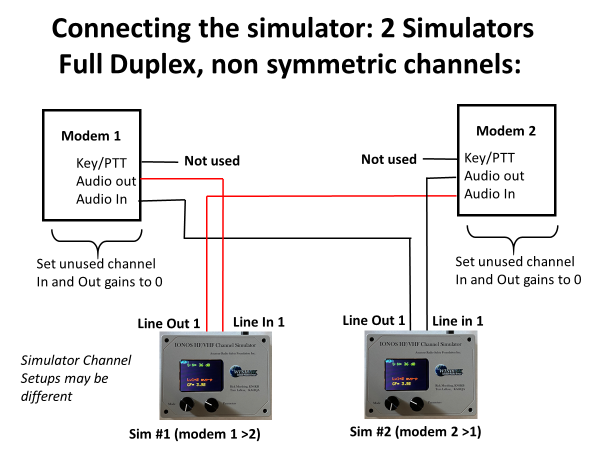
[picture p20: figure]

Fig8. Full Duplex, non-symmetric channel setup using two IONOS SIMs
(note: Stereo isolation transformers can be used if ground loops affect audio quality)

4.1 Audio Levels. For proper operation the simulator must supply non-saturated, undistorted audio to the modems and receive correct level audio from the modems. The Simulator has 4 audio gain/output level controls that allow a wide independent adjustment for CH1 and CH2 input and CH1 and CH2 Outputs. There are probably also other gain adjustments (hardware or software) on the modem in and out audio. Some modems also support an auto level function. The optimum settings are those output levels that allow the modem to be driven with the required signal without overdriving or clipping and with input levels and gain settings that allow the simulator to process audio in its normal range (200 – 1200 mv p-p). The p-p level readouts shown in Modes WGN thru MPD show the actual measured pp levels inside the simulator. Take time to adjust and note the settings [Modems 1 and 2 inputs and outputs, Simulator CH1 and CH2 Inputs and Simulator CH1 and CH2 outputs] so they can be easily setup again. (Simulator gain settings can be saved to EEPROM by pushing on the right (parameter) encoder when the gain/level setting is displayed). Input gains and output levels are adjustable over a wide logarithmic range. If an input gain or output level is too large for the dynamic range of the simulator (levels shown in RED) it may cause clipping and distortion of the audio signal. One suggested mechanism for setting the proper level signal into the simulator is:

1)Connect one modem output to the simulator (In1 or In2). If there is any noise or hum introduced by ground loops using a stereo line isolator (transformer) in the audio to/from the simulator has been shown to help.

2) Set the simulator up for the desired channel mode (WGN through MPP). This will show the input signal p-p readings (“Lvl =”) on the Ch1 In or Ch2 in lines.
3) Adjust the output of the modem to fall within a range of 200 – 1100 (mv p-p). The level can be controlled by EITHER the modem’s output level adjustment or the appropriate CH1 or CH2 IN adjustment on the simulator.
4) The simulator Out gain settings (CH 1 OUT or CH2 OUT) can then be used to make simulator output adjustments as needed for proper modem input level. There may be additional modem input gain settings on the modem. The maximum output of the simulator is limited to 2000mv p-p
5) Repeat steps 1-4 for the other modem input and output. If using a single Simulator to model a symmetric half duplex channel make the modem outputs (to the simulator) approximately the same level or adjust the CH1 and CH2 input gains to achieve similar p-p level readings. Make test runs using the WGN mode with 20 or 30 dB S:N to verify proper setup and operation before making any extensive measurement runs. For multipath simulations Insure normal output swings to not exceed simulator Lvl limits before running extensive tests. Document all the levels used to make repeated setups easier and consistent and if desired save the Simulator Input Gain and Output Level settings to EEPROM. Note: The modem’s input and output levels may not be the same as normal operation with a transceiver since the audio input requirements and output levels from the transceiver may be different.

5.0 Manual User Interface (Right & Left Encoders). The primary user interface consists of 2 rotary encoders with push capability and a 320x240 pixel color graphics display. The Encoders allow selection of basic Modes (left encoder) and parameters (right encoder). The left encoder push function toggles less used functions on/off (e.g. Spectrum Plot). The right encoder push function togles a built in 1.5 KHz oscillator on/off for testing or saves power on default parameter values to EEPROM. Fig 9 describes the modes and parameters of the left and right encoders.

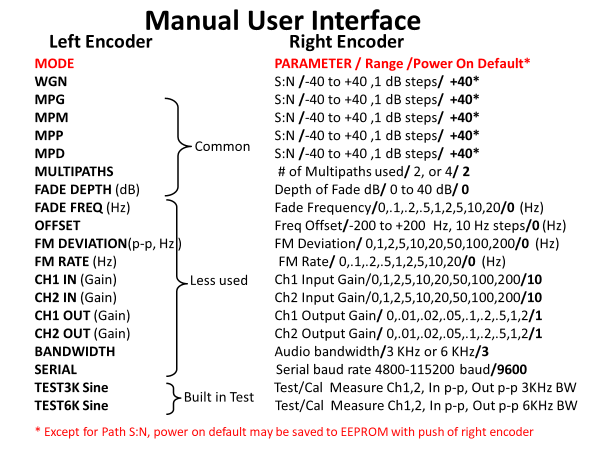
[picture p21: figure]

Fig. 9. Manual User Interface Encoders 1 and 2.

6.0 Computer interface. Although most users will find the encoder interface above simpler and easier to use an alternative USB serial interface (4800-115200 baud) is included that can allow more sophisticated and automated testing using short ASCII commands through the Simulator’s serial USB port. This will require some user supplied control or script program that sets up the simulator and modem, runs a session for a specific path type and S:N, and computes and saves performance data (e.g. average net bytes/minute transferred). This can save much time if a large number of simulations are to be run. Each command sent by the computer to the simulator must be sequenced by the correct response [ OK(Cr)] from the simulator. The commands are case insensitive standard ASCII as shown in Fig 11. If a syntax, spelling error, or parameter out of range is received by the simulator a [“?” (Cr)] is returned. The BUSY command is used for a busy detector function (section 7). The commands in Fig 10 correspond to mode and parameter settings of rotary encoders 1 and 2.

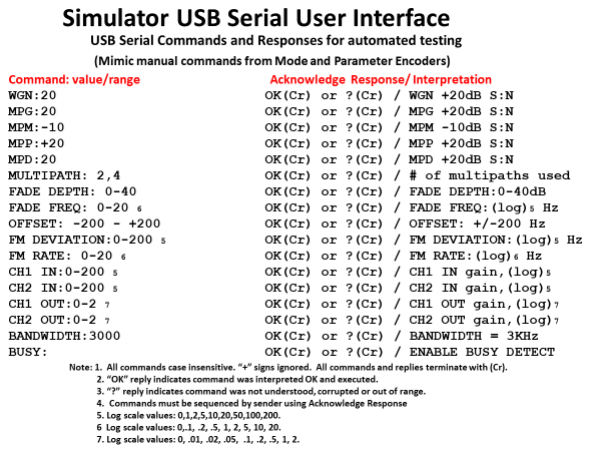
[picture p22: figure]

Fig 10. Serial Commands for Simulator Control

(note: Command “BUSY:”) is normally not used with the Simulator. It switches the IONOS SIM to a BUSY DETECT mode. See section 8.0). The SERIAL baud rate must be set manually using the Parameter encoder.

### 7.0 Basic Application of the Simulator for HF and VHF/UHF use

The use of the IONOS Sim is relatively straight forward but some care is required in setting up test to get consistent and representative test results.

7.1 Test Parameters. Most Simulation runs compare/plot net throughput (after all retries for ARQ modes) vs a specific path type and range of S:N (e.g. MPG over +20 to – 5 dB). For comparison several graphs are often shown on one chart. To obtain accurate and repeatable results requires sending sufficient data over a fairly long session (at least 5 minutes and sometimes over 10.). This is because of the nature and designed randomness of the channel modeling and the adaptation to changing channels used by adaptive modems. White Noise and multipath channel delay values use random or normal (gaussian) distributions so even with long successive runs with the same test data and parameter there will normally be some variance in net throughput values.

7.2 Test Examples for HF and VHF Testing. Fig 11 below plots the performance in net bytes/minute of five different HF protocols over a S:N range +40 to -5 dB S:N using a simulated Multi Path Poor (MPP, 2 path) channel done by Tom Whiteside N5TW using the IONOS SIM simulator. The drop off of throughput vs S:N is normal and gives a good indication of how each protocol can be expected to work at a given received S:N on a typical multipath poor channel.

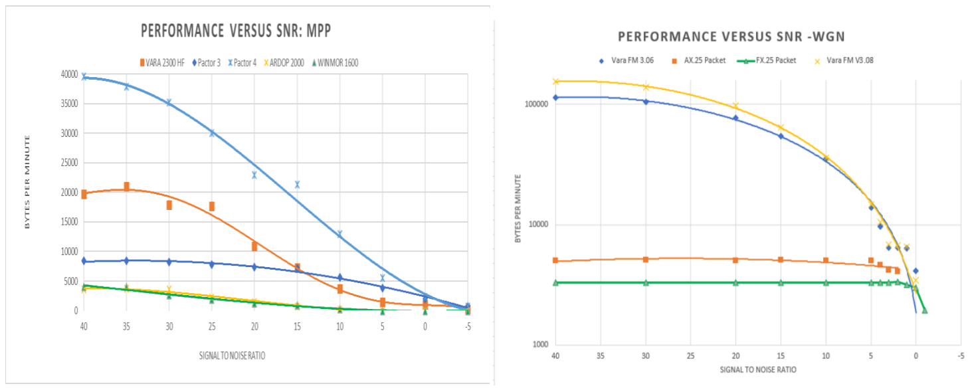
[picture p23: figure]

Fig 11: 5 HF Protocols over +40 to -5 dB S:N, MPG Fig 12: 4 VHF FM Protocols over +40 to -3 dB S:N

Figure 12 shows a simulation for 4 different VHF FM protocols over a WGN channel. Since these protocols can use wider bandwidth “audio” to the FM Modulator the IONOS SIM simulator was set for its 6KHz bandwidth option. More details on Tom’s extensive simulation efforts using the IONOS SIM simulator can be found at https://winlink.org/content/ionos_simulator To collect repeatable and representative data it is necessary for the simulations runs to be long enough to accommodate modems/protocols that use adaptive modulation and to average out the slow amplitude fluctuations due to multipath. Each “dot” or symbol in the above plots represents a typical simulator run of 5-10 minutes. Measured throughput values may be changed somewhat by the length of test and the client program used so for best accuracy these should be kept constant and noted in the test results.

To aid making many long runs when extensive testing is anticipated the IONOS SIM simulator can be computer controlled using the text commands shown in Fig 10. These example simulation cases and runs highlight why trying to obtain this kind of test accuracy and repeatability is so difficult using normal “over-the-air” radio testing.

IONOS HF/VHF Channel Simulator Specifications

Rev Nov 25, 2020 (Firmware rev 2.03)

Rick Muething KN6KB, Tom Lafleur KA6IQA, Winlink Development Team

Description: IONOS SIM is a self-contained audio DSP based ionospheric simulator based on the Watterson Model [1] for ITU/CCIR standardized HF and VHF propagation paths (ref. CCIR/ITU 520-2, RF,1487). It uses the Teensy 4.0 CPU (ARM Cortex-M7 processor at 600 MHz) and Teensy Audio DSP Library.

Primary Use: The development, characterization, maintenance and comparison of HF and VHF modems and protocols including “sound card” protocols.

Channels Modeled: WGN (White Gaussian Noise: Spread 0 Hz, Delay: 0 ms); , MPG (CCIR Multipath Good) Spread .1 Hz, Delay .5 ms ; MPM (CCIR Multipath Moderate) Spread .5 Hz, Delay 1 ms; , MPP (CCIR Multipath Poor) Spread 1 Hz, Delay 2 ms; MPD (Multipath disturbed) Spread 2 Hz, Delay 4 ms; Flat Fading 0-40 dB, Fade Rate: .1-20 Hz; Fixed Freq offset +/- 200 Hz, 10 Hz steps; Slow FM deviation +/- 1-200 Hz, Rate .1 to 20 Hz; Multipath update rate 64x Doppler spread. Fade, offset, and FM can be combined with mode WGN.

Audio Paths: WGN: 1 path. Multipath: 2 or 4 I&Q paths. Input to Output Delay: Min 3.5ms (WGN); Max 8 ms (Multipath Disturbed). Multipath 2 paths: I2, Q2 Paths delayed by .5, 1, 2, or 4 ms.
Multipath 4 paths: 12,Q2 Paths delay by .25, .5, 1, or 2 ms I3,Q3 paths delayed by .5, 1, 2, or 4 ms.
I4,Q4 paths delayed by .75, .1.5, 3, or 6 ms

Connections Modeled: 1 Simulator: Half duplex, both sides, symmetric channel models. 2 Simulators: Full Duplex both sides: symmetric or asymmetric channel models.

Bandwidths: 3 KHz: 300 Hz to 3.3 KHz, 6 KHz: 300 Hz to 6.3 KHz. +/- 1dB Sampling rate: 44.1 KHz

Noise modeling: WGN filtered to 3 KHz or 6 KHz bandwidth. S:N -40 to +40 dB, 1 dB steps.

Inputs: Ch1, Ch2 via standard Stereo 1/8” (3.5 mm) jack. AC coupled. Input protection. Impedance > 50KOhms. Nominal input range: 10 – 1800 mv p-p. Manual input level control. Internal simulator level and input crest factor (CF) displayed.

Outputs: Ch1, Ch2 via standard Stereo 1/8” (3.5 mm) jack. AC Coupled. Short circuit protection. Impedance 150 Ohms. Nominal output range 10 - 1800 mv p-p. Manual output level control.

Power Required: Nominal 5 v (internally reg. to 3.3 V) via micro USB connector. < 200 ma.

Display: 320H x 240V pixel color TFT for Text and Graphics. (parameter settings, input level/CF, 3 & 6 KHz Spectrum Display)

Modes: Self-Test and Calibration verification to +/-1 dB Across operating BW; Setup modes and parameters;

User Parameter settings and control: Two Incremental encoders (Mode, Parameter) each with push toggle. Alternate USB serial ASCII commands for automated operation (4800-115200 baud).

Size: 6.1” (155 mm) L x 4.7” (120 mm) W x 1.4” (36 mm) H (excluding knobs).

Alternate Functions: Integrated Busy Channel Detector (experimental). Uses only serial USB ASCII command interface with host program.

[

APPENDIX:

Copyright (C) 2020 Amateur Radio Safety Foundation Inc. (ARSFI)

Licensed under the MIT Open Source Initiative.

Permission is hereby granted, free of charge, to any person obtaining a copy of this software and associated documentation files (the "Software"), to deal in the Software without restriction, including without limitation the rights to use, copy, modify, merge, publish, distribute, sublicense, and/or sell copies of the Software, and to permit persons to whom the Software is furnished to do so, subject to the following conditions:

The above copyright notice and this permission notice shall be included in all copies or substantial portions of the Software.

THE SOFTWARE IS PROVIDED "AS IS", WITHOUT WARRANTY OF ANY KIND, EXPRESS OR IMPLIED, INCLUDING BUT NOT LIMITED TO THE WARRANTIES OF MERCHANTABILITY, FITNESS FOR A PARTICULAR PURPOSE AND NONINFRINGEMENT. IN NO EVENT SHALL THE AUTHORS OR COPYRIGHT HOLDERS BE LIABLE FOR ANY CLAIM, DAMAGES OR OTHER LIABILITY, WHETHER IN AN ACTION OF CONTRACT, TORT OR OTHERWISE, ARISING FROM, OUT OF OR IN CONNECTION WITH THE SOFTWARE OR THE USE OR OTHER DEALINGS IN THE SOFTWARE.

References:

[1] Watterson, C.C., J.R. Juroshek, & W.D. Bensema. 1970 Experimental confirmation of an HF channel model IEEE Transaction of Communication. Technology. Vol COM-18. Pp 792-803 Dec 1970
[2] Simulation of Communications Systems Michel C. Jeruchim, Philip Balaban, & K.Sam Shangmugan 1992 Plenum Press. ISBN 0-306-53989-1
[3] UNDERSTANDING HF CHANNEL SIMULATOR REQUIREMENTS IN ORDER TO REDUCE HF MODEM PERFORMANCE MEASUREMENT VARIABILITY W. N. Furman and J.W. Nieto Harris Corporation, RF Communications Division 1680 University Avenue, Rochester, New York, 14610 U.S.A.
[4] CCIR/ITU Rec. 520-2 1 9E2c: Influence of the ionosphere RECOMMENDATION 520-2 USE OF HIGH FREQUENCY IONOSPHERIC CHANNEL SIMULATORS (1978-1982-1992)
[5] PathSim User and Technical Guide Ver. 1.0 Dec 1, 2000 Moe Wheatley, AE4JY www.moetronix.com/ae4jy/files/pathsimtech100.pdf
[6] A Low-Cost HF Channel Simulator for Testing and Evaluating HF Digital Sytems Johan B. Forrer, KC7WW ARRL/TAPR DCC 1999

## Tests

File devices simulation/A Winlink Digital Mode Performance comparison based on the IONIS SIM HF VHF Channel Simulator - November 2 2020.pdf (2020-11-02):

Page 1 of 25

## A comparison of Winlink® digital mode performance based on simulation results using the Teensy IONOS Simulator¹ - Take Three

### By Tom Whiteside, N5TW

The “Take Three” in the title refers to this being yet another significant revision from the earlier version. In a post graduate simulation course, the professor stated that a San Francisco traffic simulator was found to have traffic routed in the opposite directions 10 YEARS AFTER THE SIMULATION WAS PUT INTO USE! His point was to never stop questioning the assumptions a simulation is based on. We are very grateful to Peter Helfert of the SCS Spezielle Communications Systeme GmbH & Co. for his helpful insights isolating additional areas where our simulator needed work to realistically look like a real channel and with much better signal to noise agreement with the real world. After Rick Muething made these changes, the results for PACTOR 4 improved significantly relative to other modes.

Executive Summary:

Hardware SCS modems running PACTOR 2,3 and 4 were evaluated as were sound card modes WINMOR, ARDOP and VARA across a variety of channel models and across a range of signal to noise conditions for HF. VARA testing included a new VARA 500 500Hz mode. VARA FM and AX.25/FX.25 packet were simulated for a VHF channel.

Spoiler alert: The SCS modems did very well as you would expect with PACTOR 4 dominating all other HF modes over the range of tests performed. The much less expensive VARA HF did well across the range of conditions

1
See “IONOS SIM HF/VHF Channel Simulator BUSY DETECT Busy Channel Detector Instructions and Basic Documentation” by Rick Muething KN6KB https://winlink.org/content/ionos_simulator

Page 2 of 25

tested. The SCS modems and VARA could run long test cases without losing a connection while ARDOP and WINMOR were slow and less reliable for lower SNR MP cases. VARA FM crushed AX.25/FX.25 VHF cases.

Overview:

Rick Muething, KN6KB and Tom Lafleur, KA6IQA developed an inexpensive yet sophisticated simulator that models standard HF and VHF propagation channels based on the Arduino Teensy. Both Rick and Tom are members of the Winlink Development Team and Amateur Radio Safety Foundation, Inc.

2
(ARSFI) board members.
Tom is responsible for the hardware design and Rick developed the software.

Simulator testing is important for creating and evaluating digital mode performance in a consistent, repeatable way that simply cannot be done with over-the-air testing where conditions are always changing. These simulators have been quite expensive in the past, typically costing many thousands of dollars. With today’s single chip micros and DSP libraries, Rick and Tom were able to create this simulator with a total parts cost of less than $200.

This simulator was used to evaluate the digital modes supported on the Winlink system over statistically standardized channels of White Gaussian noise and multipath with noise cases across a range of signal to noise values. These channels are based on the well-documented Watterson model³ used in many expensive laboratory grade instruments.

For HF, both wideband (>2KHz) modes (PACTOR 3, PACTOR 4, VARA 2300, ARDOP 2000 and WINMOR 1600) and 500Hz modes (PACTOR 2, ARDOP 500, WINMOR 500 and an all new VARA 500 mode) were tested.

For VHF, AX.25 based packet, FX.25 based packet and VARA FM were tested.

2 Amateur Radio Safety Foundation, Inc. https://www.arsfi.org/
3 Watterson, C.C., J.R. Juroshek, & W.D. Bensema. 1970 Experimental confirmation of an HF channel model IEEE Transaction of Communication. Technology. Vol COM-18. Pp 792-803 Dec 1970

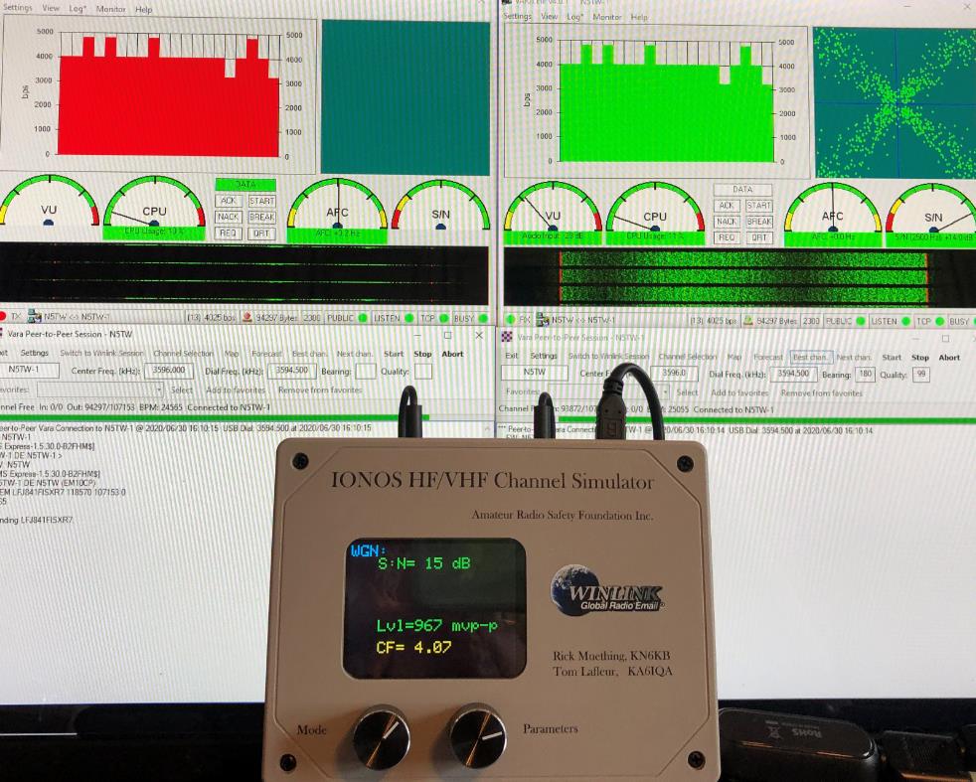
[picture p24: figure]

Page 3 of 25

No simulator can create all the band conditions, QRM, aurora and other effects we can encounter but these results should be a good comparison of performance over a wide range of conditions. All data presented (bytes/minute) is net after FEC corrections, needed repeats and modulation shifts required by the protocols.

Figure 1 Test setup at N5TW using the IONOS Simulator
Here are those results:

HF Testing:

The first case evaluated was for wide HF Winlink Digital Modes over a range of signal to noise ratios using White Gaussian noise.

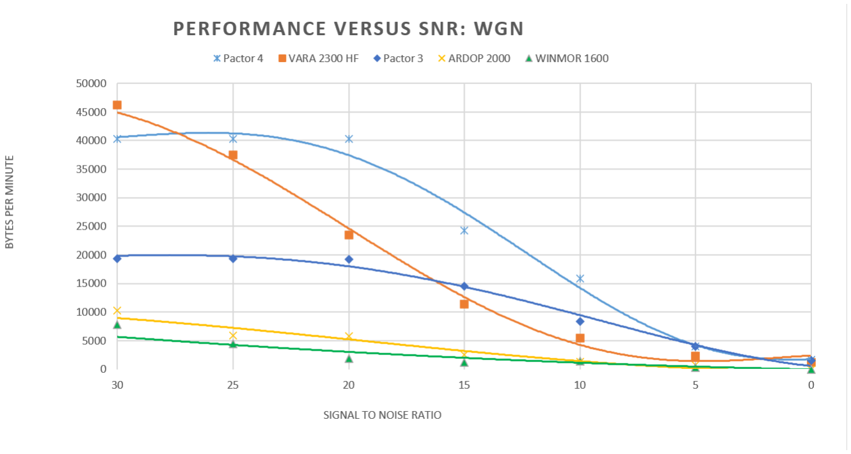
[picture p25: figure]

Page 4 of 25

All modes were able to operate over this range of signal to noise ratio. With an excellent quality 30dB SNR, VARA performance exceeds a PACTOR 4 TNC but PACTOR 4 dominates over the realistic SNR range. VARA exceeds PACTOR 3 for this model for greater than 17dB SNR conditions. ARDOP exceeds WINMOR performance for strong signals but both ARDOP and WINMOR have performance a small fraction of the speed of the other modes.

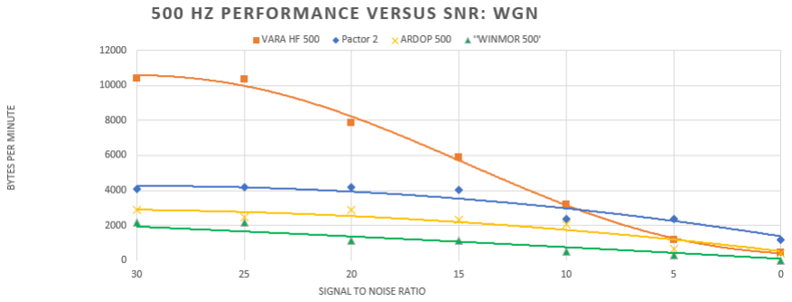
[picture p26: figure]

Page 5 of 25

Here are the White Gaussian noise results for the 500Hz HF modes:

The recently released all new VARA 500 mode dominated performance over the other modes for greater than 10dB SNR for White Gaussian noise.

Page 6 of 25

HF Multipath simulation:

The Teensy IONOS Simulator has a rich assortment of multipath test cases. In the real world, all signals experience some degree of multipath distortion whether it is a local VHF/UHF signal arriving directly as well as reflections off various objects or an HF signal experiencing different effects from the ionosphere and/or arriving via different headings. The simulator has four levels of multipath models: MPG (good conditions), MPM (moderate conditions), MPP (poor conditions) and MPD (disturbed conditions). Each of these multipath levels can be run using a 2 Path (each with I and Q) model.

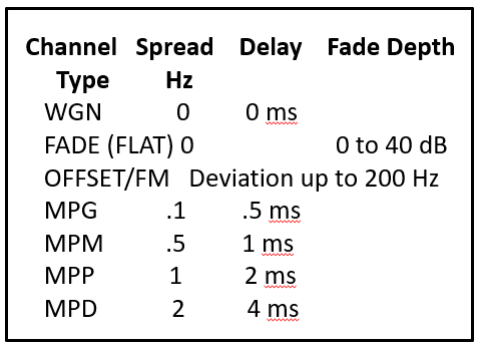
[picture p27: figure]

For the tests in this paper, the MPG and MPP levels of multipath are run all with a 2-ray model.

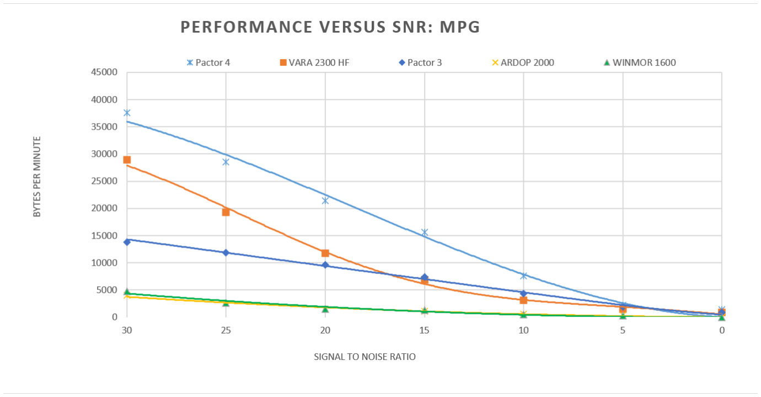
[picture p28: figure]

Page 7 of 25

Wideband (>2KHz) Multipath MPG (Good) Results:

PACTOR 4 was the clear leader in the MPG case with VARA in a respectable second place for SNRs 17dB or greater.

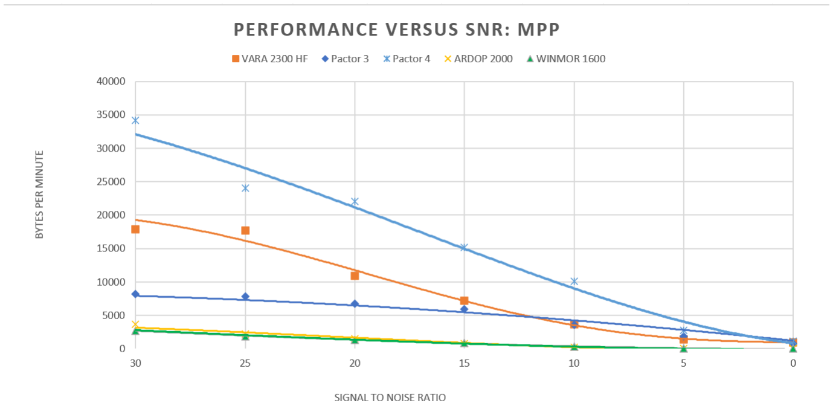
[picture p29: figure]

Page 8 of 25

Wideband (>2KHz) Multipath MPP (Poor) Results:

PACTOR 4 was again the clear winner. VARA came in second for SNRs greater than 13dB with PACTOR 3 in third place. WINMOR and ARDOP were significantly slower and often required multiple runs to get tests to complete at low SNRs.

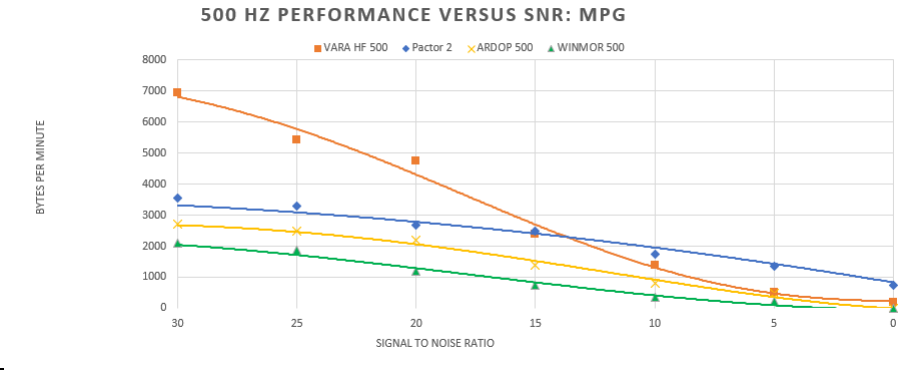
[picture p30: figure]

Page 9 of 25

Multipath MPG (Good) 500Hz Results:

VARA 500 far exceeded the other modes at 500Hz for SNR values greater than 14dB. PACTOR 2 came in second place but was the winner when the SNR was worse than 14dB. WINMOR and ARDOP performance slowed to a crawl for the low SNR cases.

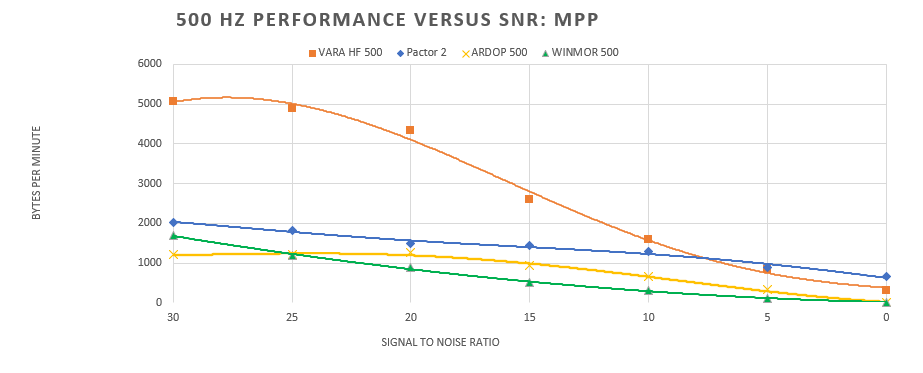
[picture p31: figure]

Page 10 of 25

Multipath MPP (Poor) 500Hz Results:

VARA held a clear lead with PACTOR 2 in second place. ARDOP and WINMOR were again much slower and often required multiple runs due to dropped links.

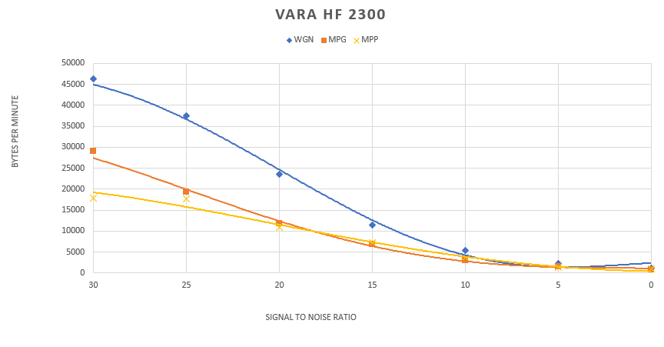
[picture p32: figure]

Page 11 of 25

Results Summary: VARA 2300

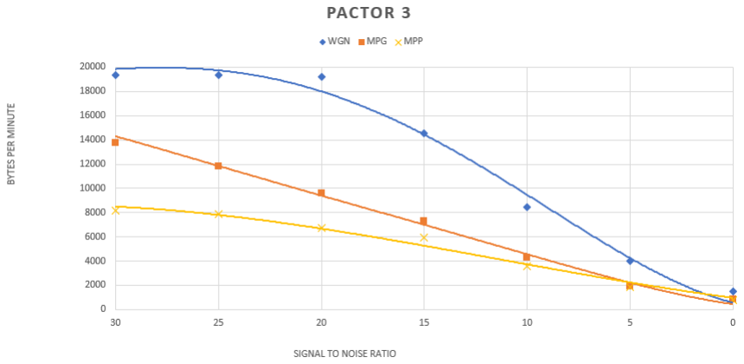
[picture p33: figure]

Page 12 of 25

Results Summary: PACTOR 3


Page 13 of 25

Results Summary: PACTOR 4


Page 14 of 25

Results Summary: WINMOR 1600


Page 15 of 25

Results Summary: ARDOP 2000


Page 16 of 25

Results Summary: VARA 500


Page 17 of 25

Results Summary: PACTOR 2


Page 18 of 25

Results Summary: WINMOR 500


Page 19 of 25

Results Summary: ARDOP 500


Page 20 of 25

FM VHF Simulator Results:

VARA FM, AX.25 Packet and FX.25 Packet were simulated. The UZ7HO Soundcard Modem⁴ was used for both AX.25 and FX.25. Andy UZ7HO recently added a beta implementation of FX.25 which was used in this testing. The results with White Gaussian noise are shown below. Because VARA FM is so much faster than packet, a log scale was used.

4
For more information on the UZ7HO Sound modem see his website: http://uz7.ho.ua/modem_beta/user_guide_v105_EN.pdf


Page 21 of 25

FX.25 has extra overhead with its inclusion of forward error correction data which can be clearly seen relative to the AX.25 plot. I could not get AX.25 to work below a 1dB SNR while FX.25 continued working to a -1dB SNR.

The plot below shows the effects on VARA FM performance versus fade depth for different fade rates with an overall White Gaussian noise 30dB signal to noise. It behaves quite well except for a slow fade. I am not sure how realistic these cases are in the environment most users would see.

Page 22 of 25

Conclusions:

I believe the Teensy IONOS Simulator is a useful tool for evaluating the various digital modes in use today and adds depth perception to over the air experience. For digital mode developers, this tool would be quite useful for evaluating new versions and experiments to supplement on-the-air testing.

Specifically, I think the data presented here is a useful comparison of the various digital modes in use with the Winlink system today. For HF users, over the entire range of conditions, the SCS PACTOR modems have outstanding performance. VARA provides excellent performance across the board. VARA is a fantastic value and held up quite well across the test cases. SCS and VARA proved extremely reliable over all the test conditions NEVER dropping a connection.

WINMOR and ARDOP were really breakthrough modes when they were first created at a time when computer/sound card technology was much less advanced than today, but their performance lags the other modes by a great deal. They were also much less reliable across the multipath cases with incredibly low rates and frequent connection drops.

Many thanks to Rick Muething for many hours of support during this project and for running the “Take Three” PACTOR cases. One benefit from this systematic testing and Rick’s efforts is a simulator that I feel people can have confidence in. And special thanks to Peter Helfert for his considerable assistance with a resulting better simulator and setting the record straight on PACTOR 4.

73,

Tom Whiteside N5TW

Page 23 of 25

## Appendix – Test Methodology

This section is included as an aid for people wanting to reproduce these results or perhaps wanting to evaluate additional conditions or future digital modes.

Tests were run using two Winlink Express instances and running peer to peer sessions to send data through the simulator to each other.

Here is a high-level pictorial of the test setup:


Page 24 of 25

As you can see, only one simulator was needed for this testing. All is done with audio – there are no radios used in these runs.

PACTOR 3 and 4 testing was done using two SCS DR-7800 TNCs. All inputs and outputs were run through isolation transformers to connect to the simulator to ensure there were no ground loops.

All sound card-based modes used two Masters Communications DRA-30 sound cards:

Page 25 of 25

http://www.masterscommunications.com/products/radio-adapter/dra/dra30.html
As with PACTOR testing, all sound card inputs and outputs were run through isolation transformers to prevent ground loops.

The Teensy IONOS SIM has a loop test menu that I used to set the output levels for the modes to ensure the signal was reasonable to not overrange any of the hardware. To do this, I first removed the output connector from the simulator and sent a test signal from each Winlink Express and adjusted output levels for around 450mV. That provides plenty of input but away from overrange limits.

Input levels were adjusted on the sound cards and the Windows sound level menus for signal levels that stayed within the “green zones” for the various apps. I did this using low SNR multipath settings where the levels can swing to the highest values. I used the simulator default input and output levels of 2V for all testing.

The simulator 3KHz bandwidth was used for all HF testing. 6KHz bandwidth was used for FM testing,

I used large data transfers to give the mode time to do its best and to average out variations. Transfer sizes of 120KB were used for high rate VARA and Pactor cases dropping to 32KB for smaller cases for these modes. For the slower WINMOR and ARDOP modes, sizes ranged from 10KB to 4KB with the smaller sizes for the especially slow cases.

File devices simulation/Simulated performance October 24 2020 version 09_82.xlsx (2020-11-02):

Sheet: HF Wide
VARA 4.0
SNR | File Size | WGN |  |  | File Size | MPG 2 | File Size | MPG 4 | File Size | MPM 3 | File Size | MPM 2 | File Size | MPM 4 | File Size | MPP 3 | File Size | MPP 2 | File Size | MPP 4
40 | 205451 | 46227 |  |  | 205451 | 31158 |  |  |  |  | 205451 | 31054 |  |  |  |  | 205451 | 19711
35 | 205451 | 46055 |  |  | 205451 | 31284 |  |  |  |  | 205451 | 29038 |  |  |  |  | 205451 | 21031
30 | 205451 | 46208 |  |  | 205451 | 28972 |  |  |  |  | 205451 | 30374 |  |  |  |  | 205451 | 17911 | 17160 |  | File Size
25 | 205451 | 37490 |  |  | 205451 | 19282 |  |  |  |  | 205451 | 29806 |  |  |  |  | 205451 | 17694
20 | 205451 | 23511 |  |  | 205451 | 11745 |  |  |  |  | 205451 | 21141 |  |  |  |  | 205451 | 10945
15 | 205451 | 11446 |  |  | 137017 | 6829 |  |  |  |  | 205451 | 18103 |  |  |  |  | 137017 | 7215 | 6098
10 | 205451 | 5456 |  |  | 68731 | 3060 |  |  |  |  | 205451 | 10157 |  |  |  |  | 137017 | 3672
5 | 68925 | 2331 |  |  | 19392 | 1482 |  |  |  |  | 137017 | 5613 |  |  |  |  | 19392 | 1421
0 | 19392 | 1158 |  |  | 19392 | 839 |  |  |  |  | 68731 | 1977 |  |  |  |  | 19392 | 988 | 1057
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

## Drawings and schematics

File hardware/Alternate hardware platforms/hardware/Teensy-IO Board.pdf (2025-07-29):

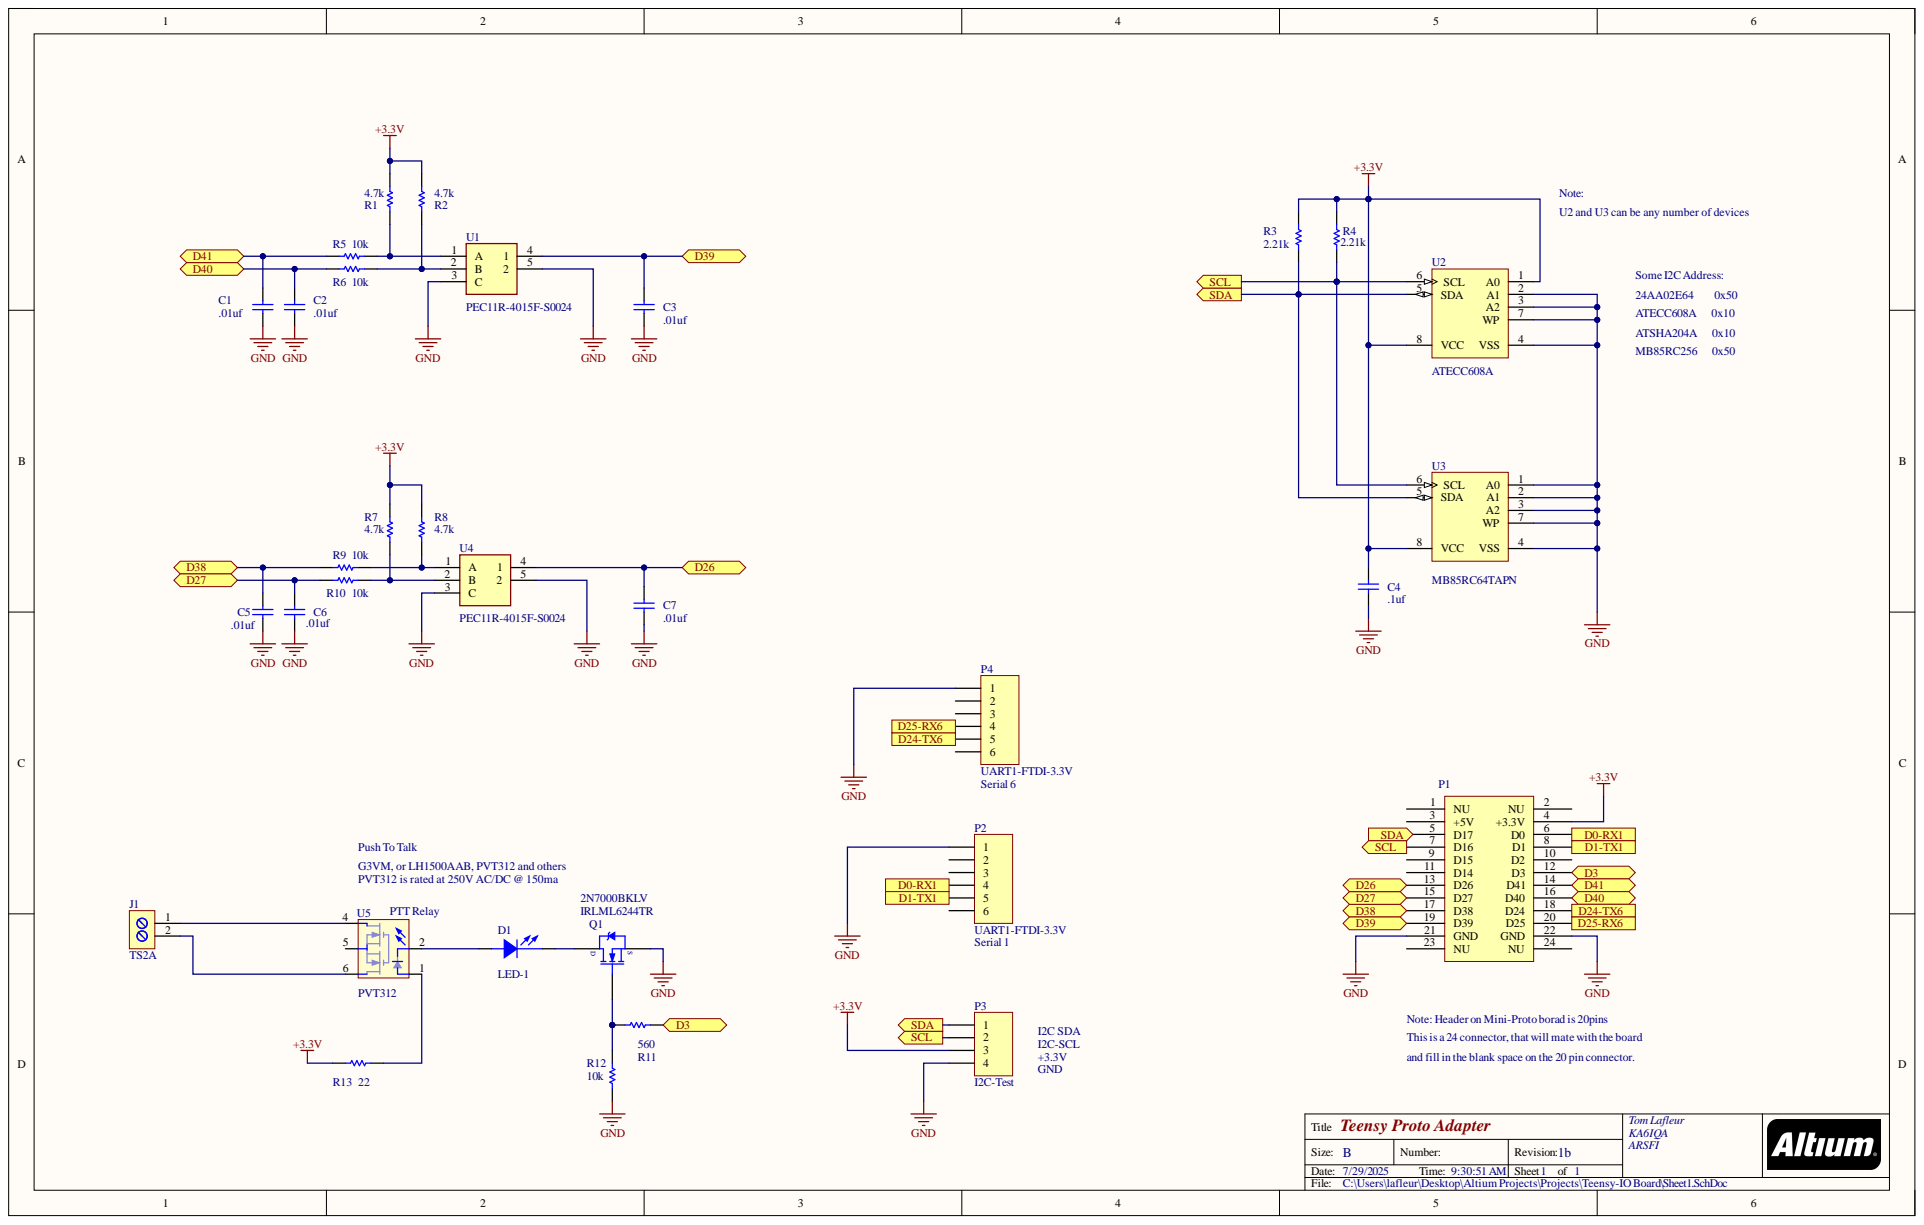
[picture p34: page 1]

Note:
U2 and U3 can be any number of devices

Push To Talk
G3VM, or LH1500AAB, PVT312 and others
PVT312 is rated at 250V AC/DC @ 150ma

Note: Header on Mini-Proto borad is 20pins
Thisis a 24 connector, that will mate with the board
and fill in the blank space on the 20 pin connector.

Title Teensy Proto Adapter | TomLafleur KA6IQA ARSFI

Size: B | Number: | Revision: 1b
Date: 7/29/2025 Time: 9:30:51 AM | | Sheet 1 of 1

C:\Users\lafleur\Desktop\Altium Projects\Projects\Teensy-IOBoard\Sheet1.SchDoc

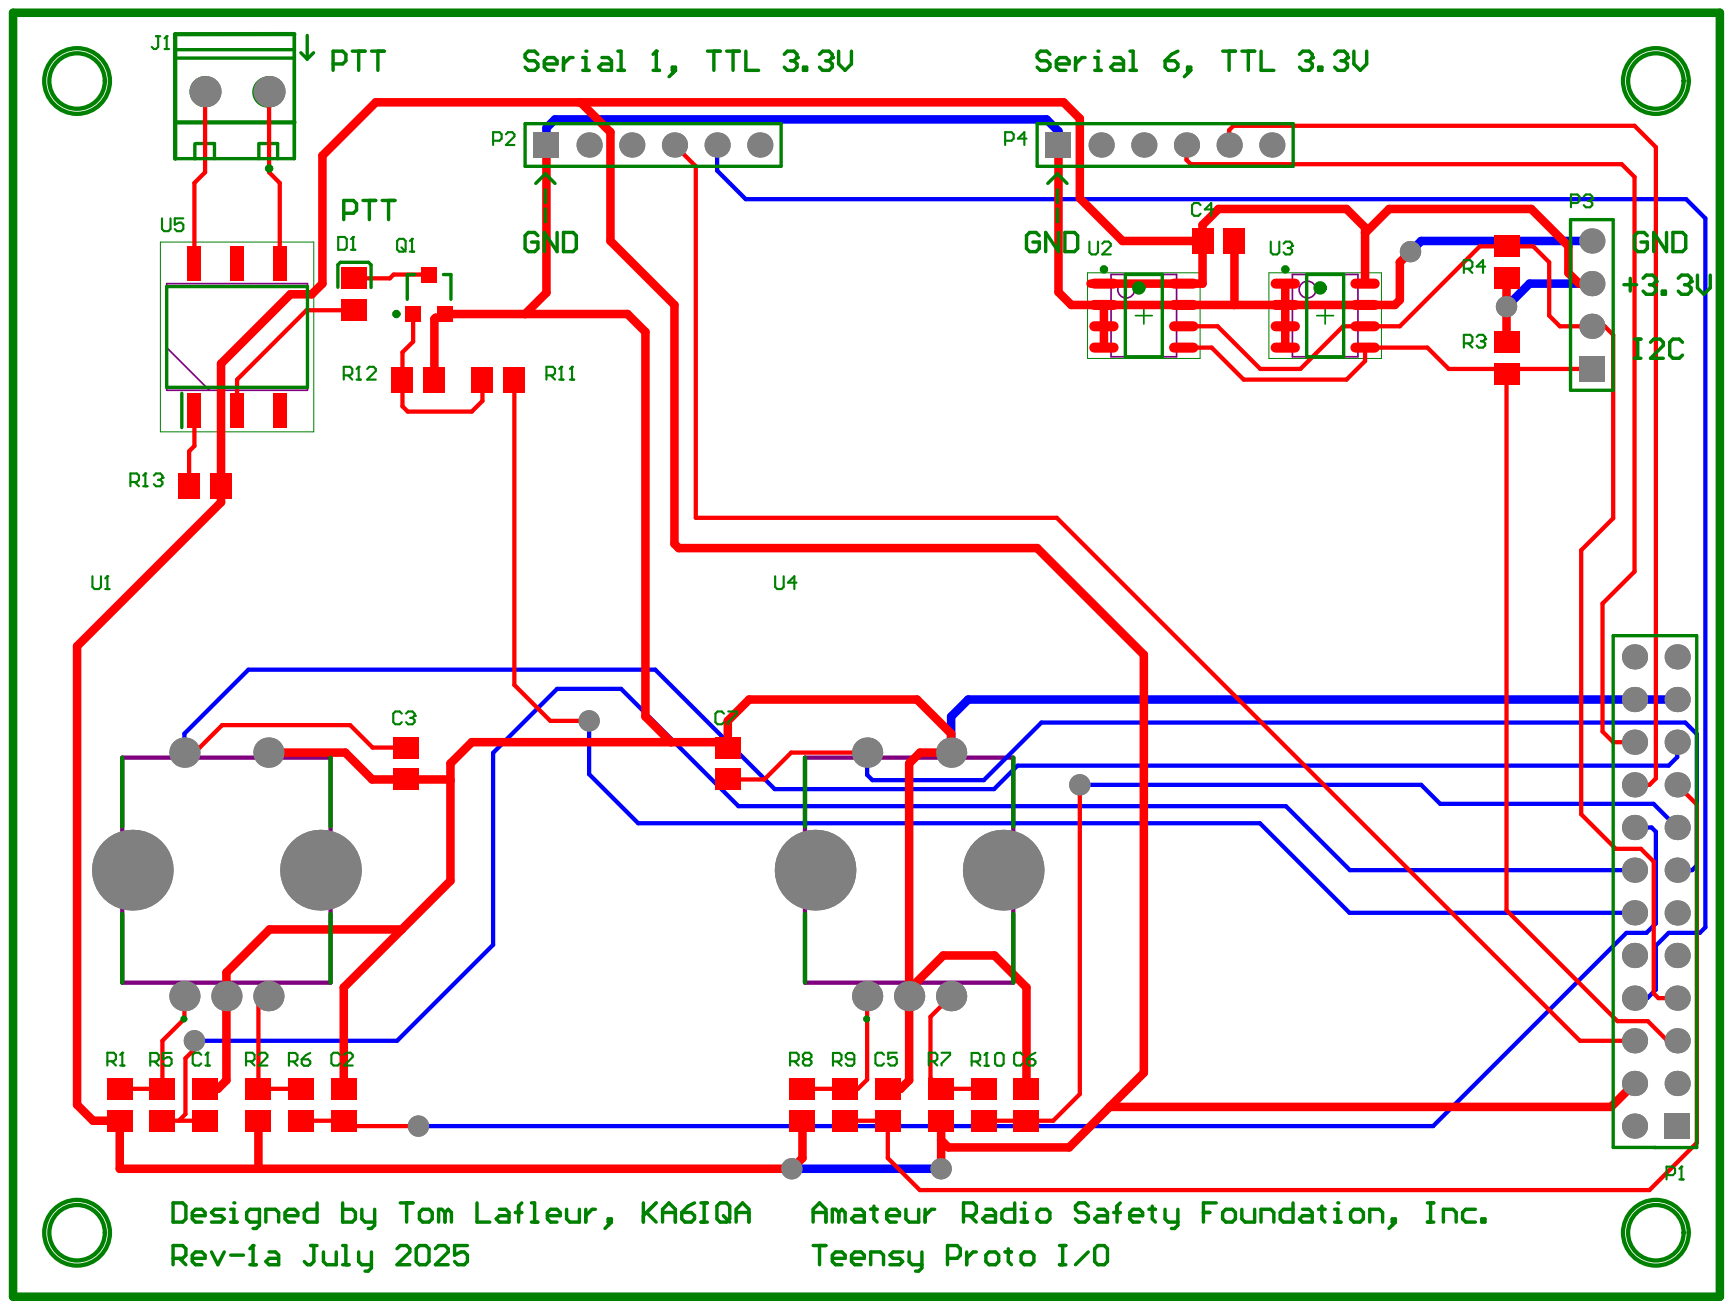
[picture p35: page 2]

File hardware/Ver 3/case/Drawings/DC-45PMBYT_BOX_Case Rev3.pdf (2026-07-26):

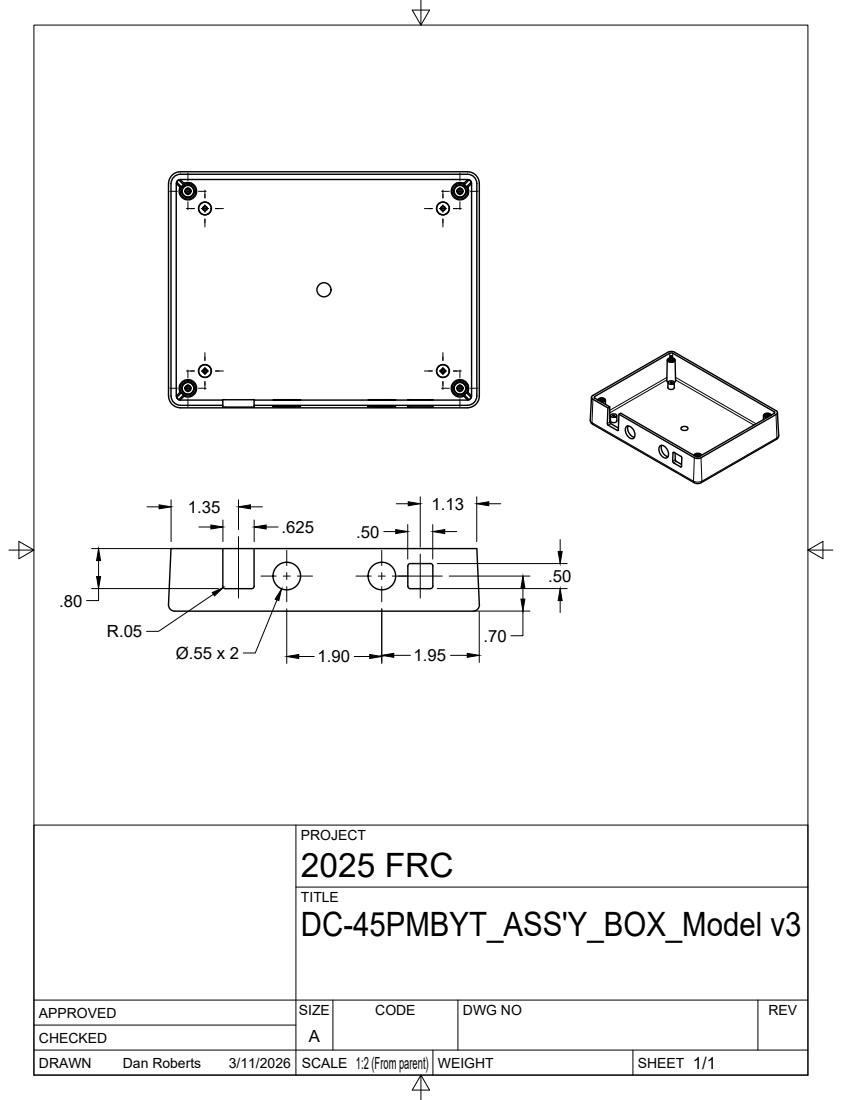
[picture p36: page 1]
SIZE; CODE; DWG NO; REV; Dan Roberts; 1:2 (From parent); 2025 FRC; DC-45PMBYT_ASS'Y_BOX_Model v3

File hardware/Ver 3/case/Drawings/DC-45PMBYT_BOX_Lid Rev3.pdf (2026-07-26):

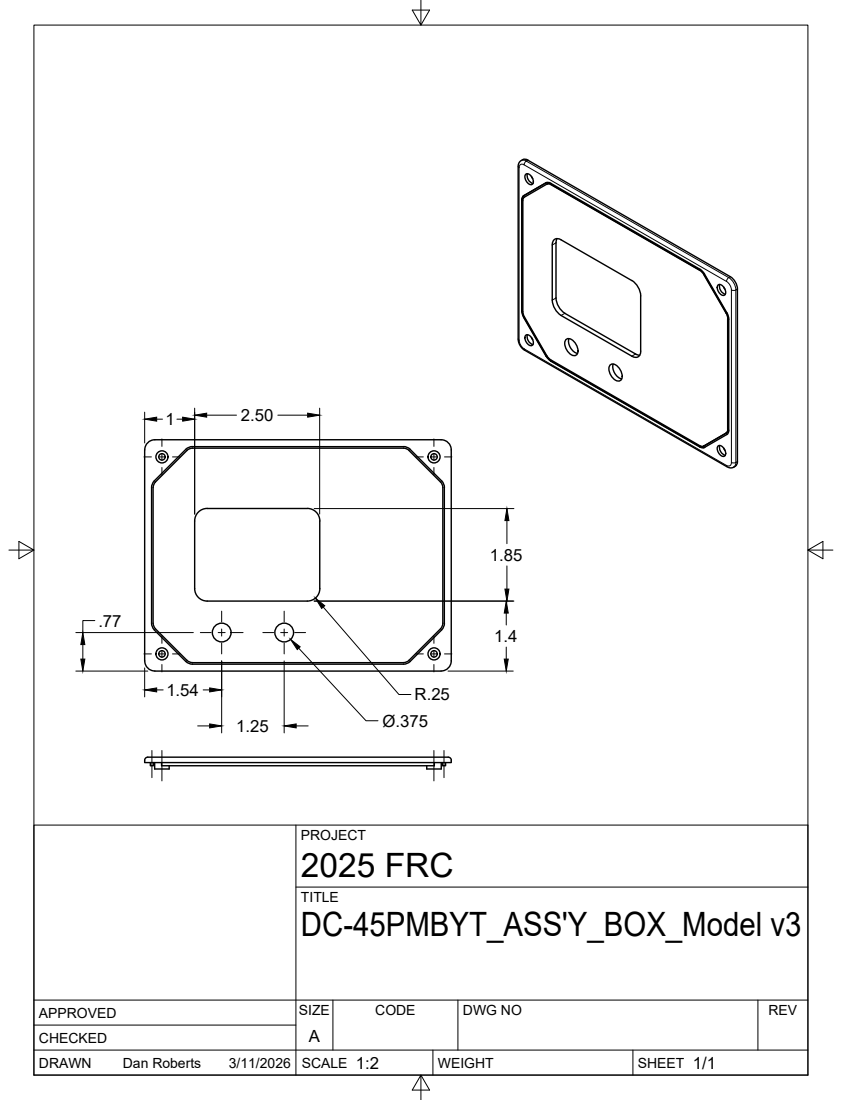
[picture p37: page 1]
SIZE; CODE; DWG NO; REV; Dan Roberts; 2025 FRC; DC-45PMBYT_ASS'Y_BOX_Model v3

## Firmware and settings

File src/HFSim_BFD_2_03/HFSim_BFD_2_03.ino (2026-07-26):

 /*  IONOS SIM HF/VHF Channel Simulator  Rick Muething, KN6KB  rmuething@cfl.rr.com
       Copyright (C) 2020  Amateur Radio Safety Foundation Inc. (ARSFI)
       Licensed under the MIT Open Source Initiative.
       
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
    Change  Log:
    Date:     Rev:      Description:
    11/17/2020   2.03   Modify multipath delay settings for 4 path mode as suggested by Peter Helfert.

    11/7/2020    2.02   Make mods to 4 path implementation and re calibration fltSTD values for correct long term average level.
    
    11/1/2020    2.01   Begin of experimental version to support 2 or 4 multipath Using 1.01 as a starting point
    11/1/2020           basic connection and duplication of Gauss filter in and compiles...not tested yet
                        Selection and save/recall from EEPROM for Multipat =2 or = 4 in and tested.
                        Modify Path processing to use two 4 input muxes for a total of 8 paths if Multipaths = 4
                        Do complete evaluation of modes and gains to allow recalibration
   
                        
    
    10/17/202    1.01   Preliminary ready for production release. No technical changes from Rev .9.82
                        Remove revision notes prior to .9.82 (Still available in old backups)
                        Edit line # used in debug printing. Add TFT Mode display update after serial command. 
                        Known issues: 1) Still ~4 dB calibration offset. 2) Busy Detector not rechecked/verified  
    
    10/4/2020    .9.82  Added rms Measure rmsDelayI0 to Delay I1 Tap to facilitate rms average computation
                        Insured nominal Input 1 of MixIQ set to .8498 on all WGN modes to insure no out of limits 
                        Re adjust calibration factor to 4.28 dB to match response of version .9.81
                        Used a separate p-p input measure (faster response than sliding Window) to display internal Lvl (mvp-p) 
// Unused area for future comments (remove as comments added) 

























     This is line #50
    Summary of Simulation Modes and ranges:

    HF/VHF  Channel Modes
    Channel     Spread     Delay                      Range                         Notes:
    Type(mode)  Hz 2Sigma    ms
    WGN (0)        0          0                                                   Also used with Flat fading or FM Deviation on VHF/UHF modeling
    MPG (1)        .1         .5                                                  CCIR Multipath Good (CCIR/ITU)
    MPM (2)        .5         1                                                   CCIR Multipath Moderate (CCIR/ITU)
    MPP (3)        1          2                                                   CCIR Multipath Poor (CCIR/ITU)
    MPD (4)        2          4                                                   Multipath Disturbed
    FADE DEPTH(6) 0                            0 to 40dB, 1dB steps               Flat Fading (depth) Can be used with all ch types
    FADE FREQ(7)                               0,.1,.2,.5,1,2,5,10,20 Hz          Flat Fading (rate) Can be used with all ch types
    OFFSET(8)                                  -200 to + 200 Hz steps 10Hz        Can be used with all ch types
    FM Deviation(9)                            0,1,2,5,10,20,50,100,200 Hz        Can be used with all ch types
    FM Rate(10)                                 0,.1,.2,.5,1,2,5,10,20 Hz         Can be used with all ch types
    CH1 In GAIN (11)                            0,1,2,5,10,20,50,100,200
    CH2 In GAIN (12)                            0,1,2,5,10,20,50,100,200    
    CH1 Out GAIN (13)                           0,.01,.02,.05,.1..2,.5,1,2
    CH2 Out GAIN (14)                           0,.01,.02,.05,.1..2,.5,1,2
    BANDWIDTH(15)                               3000,6000 Hz
    SERIAL iinterface rate (16)                 4800,9600,14400,19200,38400,57600,115200 baud
    TEST3K                                      Test/Calibration 3000Hz BW        Test Freq 300 - 3300 Hz, 100 Hz steps
    TEST6K                                      Test/Calibration 6000Hz BW        Test Freq 300 = 6300 Hz, 200 Hz steps               
    
    OFFSET and FM modeling can be used with any channel type and adds a fixed offset or VLF sine wave (FM Deviation) to the Down mixer LO
*/

//Libraries
#include <Audio.h>
#include <Wire.h>
#include <SPI.h>
#include <Bounce2.h>
#include "Encoder2.h"
//#include "SPI.h"
#include "ILI9341_t3.h"
#include <EEPROM.h>

Encoder2 ENC1(1, 0); // (right) modes
Encoder2 ENC2(4, 3); // (left) parameters

// For the Adafruit shield  ILI9341, these are the default. (Pin 6 below was Pin 9. RM 3/2/2020)
#define TFT_DC  6
#define TFT_CS 10
#define ENC1Button 2//Right (parameter) 
#define ENC2Button 5//Left  (mode)

//Code for Serial Numbers (These two 32 bit numbers are used to generate MAC address (not used) and 4 digit Serial Number. 
#define OCOTP_CFG0 (*(uint32_t *)0x401F4410)// lower 13 bits define the "Serial Num" ( & with 8191)
#define OCOTP_CFG1 (*(uint32_t *)0x401F4420)// currently not used.

Bounce debouncer1 = Bounce();
Bounce debouncer2 = Bounce();
ILI9341_t3 tft = ILI9341_t3(TFT_CS, TFT_DC);

// Teensy Audio components (currently 35 components used) 
AudioControlSGTL5000            sgtl5000_1;
AudioInputI2S                   i2s0;
AudioOutputI2S                  i2s1;

AudioFilterFIR                  filLPIn_0_FIR;  // Input LP Filter
AudioFilterFIR                  filLPWhiteFIR; // Low pass filter for White noise
AudioFilterFIR                  filHP7500FIR; // Highpass for up mixing 7500 Hz Injection Freq
AudioFilterFIR                  filLPDownMix; // LowPass filter for Down Mixing 7500 nominal (no shift) injection freq.
AudioFilterFIR                  filHilQ_1234; // Hilbert FIR filter for Q1, Q2, Q3, Q4 channels

AudioSynthWaveformSine          InputTestWaveform; // Used to provide single tone test signal to make measurements at various points.
AudioSynthWaveformSine          sine_Upmix;  // 7.7 KHz Upmix for Low Freq Offset/drift  testing
AudioSynthWaveformSineModulated sine_Dnmix;  // ~7.7 KHz Down mix injection for Low Freq Offset/drift testing
AudioSynthNoiseWhite            whiteOut;   // White noise to add to Channels for S:N
AudioSynthWaveformSine          sine_VLF_Dnmix_Mod;// Slow VLF modulation feeds sine_Dnmix modulation input.

AudioEffectDelay                delayI; // Delay for audio I paths 1, 2,(multi tap)
AudioEffectDelay                delayQ; // Delay for audio Q paths 1, 2,(multi tap)
AudioEffectMultiply             multUpmix;// Multiplier for Upmixing 7500 Hz
AudioEffectMultiply             multDnmix;// Multiplier for Downmixing ~ 7500 Hz
AudioEffectMultiply             multI2;// Multiplier for true rms measure of I input
AudioEffectMultiply             multITap7; //Multiplier for squaring I delay tap # 7 

AudioMixer4                     mixIQ12;// Mixer to combine  Delays for paths 1 and 2
AudioMixer4                     mixIQ34;// Mixer to combine  Delays for paths 3 and 4
AudioMixer4                     mixIQ1234;// Mixer to combine mixIQ12 and mixIQ34
AudioMixer4                     mixChannels;// Mixer to combine ch 1,2,3,4  and White Noise
AudioMixer4                     mixInpSel;// Mixer to select InputTestWaveform, or external inputs 1(L) or 2 (R) 
AudioMixer4                     mixPathSel;// Mixer to select direct path or Up/Down mixer path
AudioAmplifier                  ampLeftOut;// Amp for gain control Left Output
AudioAmplifier                  ampRightOut;//Amp for gain control Right Output

AudioAnalyzePeak                ppLPInput; //p-p value of the filLPIn_0_FIR output
AudioAnalyzePeak                ppi2s0In;//  Probe to measure input i2s0 p-p value (Used in auto test and Auto level)
AudioAnalyzePeak                ppi2s1In;//  Probe to measure input i2s1 p-p value (Used in auto test and Auto level)
AudioAnalyzePeak                ppAmpRightOut;// Probe to measure AmpRightOut p-p value (Used in auto test)
AudioAnalyzePeak                ppAmpLeftOut;// Probe to measure AmpRightOut p-p value (Used in auto test)
AudioAnalyzeRMS                 rmsLPInput;//  rms probe to compute rms value of filLPIn_0_FIR output
AudioAnalyzeFFT1024             fft1024; //  FFT analysis and Spectrum plotting
AudioAnalyzeRMS                 rmsMixIQ1234Out; // RMS measure of mixIQOut34 for Average computation
AudioAnalyzeRMS                 rmsNoise; // Probe to compute rms of BW filtered WGN 
AudioAnalyzeRMS                 rmsDelayI0;  //Probe to compute rmsValue of output of Delay I0 tap.

// Audio Connections  (for a total of 2 audio paths through the simulator each path containing I and Q paths)
AudioConnection           pcInp_1(InputTestWaveform, 0, mixInpSel, 0);//Test sine wave to input 0 of input mixer
AudioConnection           pcInp_2(i2s0, 0, mixInpSel, 2);// Input pin 0 of  i2s0 to input 2 of input mixer (Left)
AudioConnection           pcInp_3 (i2s0, 1, mixInpSel, 3);// Input pin 1 of  i2s0 to input 3 of input mixer (Right)
AudioConnection           pcInp_4(i2s0, 0, ppi2s0In, 0); // p-p measurement of input i2s0 pin 0
AudioConnection           pcInp_5(i2s0, 1, ppi2s1In, 0); // p-p measurement of input i2s0 pin 1

// Audio Connections mixInpSel through to inputs (normal and offset/modulated) t0 mixAudioSelect inputs 0(normal) and 1(offset/modulated)
AudioConnection           pc0_1(mixInpSel, filLPIn_0_FIR); //Input mixer to filLPIn_FIR;  
AudioConnection           pc0_2(filLPIn_0_FIR, 0, multUpmix, 0);// filLPIn to Upmixer
AudioConnection           pc0_3(filLPIn_0_FIR, 0, mixPathSel, 0);//filLPIn to mixPathSel
AudioConnection           pc0_4(sine_Upmix, 0, multUpmix, 1);// Upmix L.O. injection 7.7 KHz
AudioConnection           pc0_5(multUpmix, filHP7500FIR);// Upmix to HPFilter.
AudioConnection           pc0_6(sine_VLF_Dnmix_Mod, 0, sine_Dnmix, 0); // Modulation input to sineDnmix
AudioConnection           pc0_7(sine_Dnmix, 0, multDnmix, 1);// Dnmix L.). injection ~ 7.7 KHz
AudioConnection           pc0_8(filHP7500FIR, 0, multDnmix, 0);// HP7500FIR to DownMix mult
AudioConnection           pc0_9 (multDnmix, filLPDownMix);// Down Mix to filLPDnMix
AudioConnection           pc0_10 (filLPDownMix,0, mixPathSel,1);//filLPDownMix to mixPathSel

// filLPDownMix output through summed I & Q  Outputs of Channels 1 & 2 (4 rays total)
AudioConnection           pc1_1(mixPathSel, delayI);// mixPathSel   to delay I (no boxcar filter ) 
AudioConnection           pc1_2(mixPathSel, filHilQ_1234);//filLPDownMix to filHilQ_1234
AudioConnection           pc1_3(filHilQ_1234,delayQ);// filHilQ_1234 to delay Q
AudioConnection           pc1_4(delayI, 0, mixIQ12, 1);// delayI tap #0 to mixIQ12 input 1
AudioConnection           pc1_5(delayI, 1, mixIQ12, 3);// delay1 tap #1 to mixIQ12 input 3
AudioConnection           pc1_6(delayQ, 0, mixIQ12, 0);// delayQ tap #0 to mixIQ12 input 0
AudioConnection           pc1_7(delayQ, 1, mixIQ12, 2);// delayQ tap #1 to mixIQ12 input 2
AudioConnection           pc1_8 (mixIQ12, 0, mixIQ1234,0); 

// filLPDownMix output through summed I & Q  Outputs of Channels 3 & 4 (4 rays total)
AudioConnection           pc3_1(delayI, 2, mixIQ34, 1);// delayI tap #2 to mixIQ input 1
AudioConnection           pc3_2(delayI, 3, mixIQ34, 3);// delayI tap #3 to mixIQ34 input 3
AudioConnection           pc3_3(delayQ, 2, mixIQ34, 0);// delayQ tap #2 to mixIQ34 input 0
AudioConnection           pc3_4(delayQ, 3, mixIQ34, 2);// delayQ tap #3 to mixIQ34 input 2
AudioConnection           pc3_5 (delayI,0, rmsDelayI0, 0); // Multiplier to compute I^2 for rms calculation
AudioConnection           pc3_6 (mixIQ34, 0, mixIQ1234, 1); // MixIQ34 output to mixIQ1234 Input 1 
AudioConnection           pc3_7 (mixIQ1234, rmsMixIQ1234Out); //rms measurement of mixIQ1234

// Channel outputs and Noise to mixerChannels and Amplifiers Left and Right outputs
AudioConnection           pc2_1(mixIQ1234, 0, mixChannels, 1); //mixIQ1234 output to mixChannels Input 1
AudioConnection           pc2_2(whiteOut, filLPWhiteFIR); //whiteOut to to filLPWhiteFIR
AudioConnection           pc2_3(filLPWhiteFIR, 0, mixChannels, 0); //Low pass filtered whiteOut to to mixChannels input 0 (mixChannels inputs  2,3 not used)
AudioConnection           pc2_4(filLPIn_0_FIR, ppLPInput); // filLPIn_0_FIR out t ppLPInput (note: p-p measurement)
AudioConnection           pc2_5(mixChannels, ampLeftOut); // mixChannels to LeftOutAmp for gain adjust
AudioConnection           pc2_6(mixChannels, ampRightOut); // mixChannels to RightOutAmp for gain adjust
AudioConnection           pc2_7(ampLeftOut, 0, i2s1, 0);// AmpLeftOut to headphones left ch
AudioConnection           pc2_8(ampRightOut, 0, i2s1, 1);// AmpRightOut to headphones right ch
AudioConnection           pc2_9(filLPIn_0_FIR, 0 , mixChannels, 3); //filLPIn_0_FIR to mixChannels for Busy detect
AudioConnection           pc2_10(mixChannels, fft1024);// mixChannels to FFT analysis
AudioConnection           pc2_11(ampRightOut, ppAmpRightOut); // p-p monitor for ampRightOut
AudioConnection           pc2_12(ampLeftOut, ppAmpLeftOut);// p-p monitor for ampLeftOut
AudioConnection           pc2_13(filLPIn_0_FIR, rmsLPInput);// LPDownmix output to rms measurement to allow PAPR computation.
AudioConnection           pc2_14 (filLPWhiteFIR,rmsNoise); //rms measurement of BW filtered WGN

//End of audio connections (Currently 38 connections) 

#define SCL1  16 // pin 16 for Teensy 4.0 SCL1
#define SDA1  17 // pin 17 for Teensy 4.0 SDA1
#define DISPLAY_ADDRESS1 0x72 //This is the default address of the OpenLCDp
 typedef volatile struct fir_arg_float_t
{
  float x;        // input sample x
  uint16_t nh;      // length of vector h  
  float *h;       // pointer to coefficient vector h
  float *delayx;     // pointer to delay buffer
  float r;        // output sample r
} fir_arg_float;


// Static Arrays:
static float fltLogs[] = { 0.0, .01, .02, .05, .1, .2, .5, 1.0, 2.0}; // Log values (Used [with scaling] for all parameters with log steps)
static char  *chrModes[] = {"WGN:            ", "MPG:            ", "MPM:            ", "MPP:            ", "MPD:            ","MULTIPATHS      ",
                            "FADE DEPTH:     ", "FADE FREQ:      ", "OFFSET:         ", "FM DEVIATION:   ", "FM RATE:        ",
                            "CH1 IN:         ", "CH2 IN:         ", "CH1 OUT:        ", "CH2 OUT:        ", "BANDWIDTH:      ", "SERIAL:         ", 
                            "TEST3K Sine:    ", "TEST6K Sine:    ", "BUSY:           "};
static char  *chrBusyModes[] = {"ENB BUSY:       ", "DIS BUSY:       ", "LOW:            ", "HIGH:           ",
                                "THRESH:         ", "TONE ON:        ", "TONE OFF:       ", "CH1 IN          ", "BANDWIDTH       ", "SPECTRUM:       ", "SIM:            "
                               };

//Strings
String strMode = ""; String strParameter = ""; String strRevision = "    Rev 2.03";
String strLastCF = ""; String strLastLevel = "";
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
void loop()
{
   String str1, str2, str3;
  //Code to update Rotary Encoder 2 (modes)
  lngENC2New = ENC2.read();//Encoder 2 controls Modes (Left hand knob)
  
  if ((lngENC2Old != lngENC2New) || (! blnInitialized))
    {
      if (blnSim)
        {
          intMode = intMode + (lngENC2New - lngENC2Old);
          if (intMode > 18) {intMode = 18;} //Hold at limit
          if (intMode < 0 ){intMode = 0;}
          if (intMode < 17)
            {
              blnTestMode3K = false; blnTestMode6K = false;  blnEnableTestTone = false;
              InputTestWaveform.amplitude(0);
              mixInpSel.gain(0, 0); mixInpSel.gain(1, 0.0); mixInpSel.gain(2, 100 * fltLogs[intGainLevel[0]]); mixInpSel.gain(3, 100 * fltLogs[intGainLevel[1]]);
              ampLeftOut.gain(fltLogs[intGainLevel[2]]);//sets ampLeftOut gain (0-2 (log))
              ampRightOut.gain(fltLogs[intGainLevel[3]]);//sets ampRightOut gain (0-2 (log))
              if ( ((intMode >= 1)&& (intMode <=4))  || ((intMode == 0) && (intTuneOffset == 0) && (intFMDevPtr ==0)) )
                {// Use Direct path (no Up/Down mixing
                  if (intMode == 0){mixIQ12.gain(0,0.0);mixIQ12.gain(1,.8498);mixIQ12.gain(2,0.0);mixIQ12.gain(3,0.0);};
                  // If mode != 0 above, mixIQ.gains will be set by calls to QuadGaussFIR128 @ 64 x the doppler rate
                  SetIQTapDelays(intMode);
                  mixPathSel.gain(0, .5);mixPathSel.gain(1, 0.0);;mixPathSel.gain(2, 0.0);;mixPathSel.gain(3, 0.0);
                  SetIQTapDelays(intMode);
                  blnModes = true;
                }
              else if ((intMode == 0 ) && (( intTuneOffset != 0) || (intFMDevPtr !=0)))
                {// Use Up/Down mixing
                  SetIQTapDelays(intMode);
                  mixIQ12.gain(0,0.0);mixIQ12.gain(1,.8498);mixIQ12.gain(2,0.0);mixIQ12.gain(3,0.0);SetIQTapDelays(intMode);
                  mixPathSel.gain(0, 0.0);mixPathSel.gain(1, 2.0819);;mixPathSel.gain(2, 0.0);;mixPathSel.gain(3, 0.0);
                  // Value 2.0819 calibrates mixUpDn Path gain = to direct path gain.
                  blnModes = true;
                }
              }
          if ((intMode >= 1) && (intMode <= 4))
            {
             SetIQTapDelays(intMode);
              blnModes = true; 
            }
        }
      tft.begin();
      tft.setRotation(1);
      tft.fillScreen(ILI9341_BLACK);
      if ((intMode == 0) || (! blnInitialized))//WGN
        {
          intCountrmsMixIQ1234Out = 0;
          SetIQTapDelays(intMode);
          mixIQ12.gain(0,0); mixIQ12.gain(1,.8498); mixIQ12.gain(2,0.0);mixIQ12.gain(3,0.0);
          mixIQ1234.gain(0, 1.0); mixIQ1234.gain(1, 0.0); mixIQ1234.gain(2, 0.0);mixIQ1234.gain(3, 0.0);
          //Serial.print("Line 1504: intMode = ");Serial.println(intMode);
          str1 = chrModes[intMode];  str2 = "    S:N= "; str3 = " dB";
          tft.setTextColor(ILI9341_CYAN);  tft.setTextSize(3);  tft.println(str1);
          tft.setTextColor(ILI9341_GREEN);  tft.setTextSize(3);  tft.println(str2 + intTargetSN + str3);
        }
      if ((intMode > 0) && (intMode <= 4))//MPG,MPM,MPP,MPD
        {
          intCountrmsMixIQ1234Out =0.0; 
          SetIQTapDelays(intMode);
          if (intMultipaths == 2)
            { 
              mixIQ1234.gain(0,1.0); mixIQ1234.gain(1,0.0);mixIQ1234.gain(2,0.0);mixIQ1234.gain(3,0.0);
            }
           if (intMultipaths == 4)
            { // Ch 0 and 1 gains need calibration for 4 path
              mixIQ1234.gain(0,1.0); mixIQ1234.gain(1,1.0);mixIQ1234.gain(2,0.0);mixIQ1234.gain(3,0.0);
            }  
          Serial.print("Line 1651: intMode = ");Serial.println(intMode);
          str1 = chrModes[intMode];  str2 = "    S:N= "; str3 = " dB";
          tft.setTextColor(ILI9341_CYAN);  tft.setTextSize(3);  tft.println(str1);
          tft.setTextColor(ILI9341_GREEN);  tft.setTextSize(3);  tft.println(str2 + intTargetSN + str3);
          if (( intTuneOffset != 0) || (intFMDevPtr !=0))
            {
              tft.setTextColor(ILI9341_YELLOW);  tft.setTextSize(2);  tft.println("    (no FM or Offset!)");
            }
        }
      if (intMode == 5)//MULTIPATHS
        {
          str1 = chrModes[intMode];  str2 = "    "; str3 = "";
          tft.setTextColor(ILI9341_CYAN);  tft.setTextSize(3);  tft.println(str1);
          tft.setTextColor(ILI9341_GREEN);  tft.setTextSize(3);  tft.println(str2 + intMultipaths);
        }
      if (intMode == 6) //FADE Depth
        {
          str1 = chrModes[intMode];  str2 = "    "; str3 = " dB";
          tft.setTextColor(ILI9341_CYAN);  tft.setTextSize(3);  tft.println(str1);
          tft.setTextColor(ILI9341_GREEN);  tft.setTextSize(3);  tft.println(str2 + intFadeDepth_dB + str3);
        }
      if (intMode == 7) // FADE Freq
        {
          str1 = chrModes[intMode];  str2 = "    "; str3 = " Hz";
          tft.setTextColor(ILI9341_CYAN);  tft.setTextSize(3);  tft.println(str1);
          tft.setTextColor(ILI9341_GREEN);  tft.setTextSize(3);  tft.println(str2 + String(10 * fltLogs[intFadeRatePtr]) + str3);
        }
      if (intMode == 8) //Offset
        {
          str1 = chrModes[intMode];  str2 = "    "; str3 = " Hz";
          tft.setTextColor(ILI9341_CYAN);  tft.setTextSize(3);  tft.println(str1);
          tft.setTextColor(ILI9341_GREEN);  tft.setTextSize(3);  tft.println(str2 + intTuneOffset + str3);
        }
      if (intMode == 9) //FM Deviation
        {
          str1 = chrModes[intMode];  str2 = "    "; str3 = " Hz";
          tft.setTextColor(ILI9341_CYAN);  tft.setTextSize(3);  tft.println(str1);
          tft.setTextColor(ILI9341_GREEN);  tft.setTextSize(3);  tft.println(str2 + String(100 * fltLogs[intFMDevPtr]) + str3);
        }
      if (intMode == 10) //FM Rate
        {
          str1 = chrModes[intMode];  str2 = "    "; str3 = " Hz";
          tft.setTextColor(ILI9341_CYAN);  tft.setTextSize(3);  tft.println(str1);
          tft.setTextColor(ILI9341_GREEN);  tft.setTextSize(3);  tft.println(str2 + String(10 * fltLogs[intFMRatePtr]) + str3);
        }

      if ((intMode >= 11) && (intMode < 15)) //Ch1, Ch2, IN;Out
        {
          str1 = chrModes[intMode];  str2 = "    ";
          tft.setTextColor(ILI9341_CYAN);  tft.setTextSize(3);  tft.println(str1);
          tft.setTextColor(ILI9341_GREEN);  tft.setTextSize(3); 
          if (intMode < 13) {tft.println(str2 +String(100 * fltLogs[intGainLevel[ intMode - 11]]));}// Scale up input fltLogs by 100}
          else {tft.println(str2 +String( fltLogs[intGainLevel[ intMode - 11]]));}// Scale output fltLogs by 1
        }

      if (intMode == 15)//BANDWIDTH
        {
          str1 = chrModes[intMode];  str2 = "    "; str3 = " Hz";
          tft.setTextColor(ILI9341_CYAN);  tft.setTextSize(3);  tft.println(str1);
          tft.setTextColor(ILI9341_GREEN);  tft.setTextSize(3);  tft.println(str2 + intBandwidth + str3);
        }
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

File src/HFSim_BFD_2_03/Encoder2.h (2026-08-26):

/* Encoder Library, for measuring quadrature encoded signals
 * http://www.pjrc.com/teensy/td_libs_Encoder.html
 * Copyright (c) 2011,2013 PJRC.COM, LLC - Paul Stoffregen <paul@pjrc.com>
 *
 *  Tom Lafleur, tom@lafleur.us
 *
 * Version 2.0 - Change algorithm to a table decode method... TRL 26 Feb 2020
 *
 *          https://www.best-microcontroller-projects.com/rotary-encoder.html
 *                    
 * Version 1.2 - fix -2 bug in C-only code
 * Version 1.1 - expand to support boards with up to 60 interrupts
 * Version 1.0 - initial release
 * 
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
 * THE SOFTWARE IS PROVIDED "AS IS", WITHOUT WARRANTY OF ANY KIND, EXPRESS OR
 * IMPLIED, INCLUDING BUT NOT LIMITED TO THE WARRANTIES OF MERCHANTABILITY,
 * FITNESS FOR A PARTICULAR PURPOSE AND NONINFRINGEMENT. IN NO EVENT SHALL THE
 * AUTHORS OR COPYRIGHT HOLDERS BE LIABLE FOR ANY CLAIM, DAMAGES OR OTHER
 * LIABILITY, WHETHER IN AN ACTION OF CONTRACT, TORT OR OTHERWISE, ARISING FROM,
 * OUT OF OR IN CONNECTION WITH THE SOFTWARE OR THE USE OR OTHER DEALINGS IN
 * THE SOFTWARE.
 */


#ifndef Encoder2_h_
#define Encoder2_h_

#if defined(ARDUINO) && ARDUINO >= 100
#include "Arduino.h"
#elif defined(WIRING)
#include "Wiring.h"
#else
#include "WProgram.h"
#include "pins_arduino.h"
#endif

#include "utility/direct_pin_read.h"

#if defined(ENCODER_USE_INTERRUPTS) || !defined(ENCODER_DO_NOT_USE_INTERRUPTS)
#define ENCODER_USE_INTERRUPTS
#define ENCODER_ARGLIST_SIZE CORE_NUM_INTERRUPT
#include "utility/interrupt_pins.h"

#ifdef ENCODER_OPTIMIZE_INTERRUPTS
#include "utility/interrupt_config.h"
#endif
#else
#define ENCODER_ARGLIST_SIZE 0
#endif



// All the data needed by interrupts is consolidated into this ugly struct
// to facilitate assembly language optimizing of the speed critical update.
// The assembly code uses auto-incrementing addressing modes, so the struct
// must remain in exactly this order.
typedef struct {
	volatile IO_REG_TYPE * pin1_register;
	volatile IO_REG_TYPE * pin2_register;
	IO_REG_TYPE            pin1_bitmask;
	IO_REG_TYPE            pin2_bitmask;
	    uint8_t            state;
		int32_t            position;
		uint16_t           pstate; 
		uint16_t           store;
} Encoder_internal_state_t;

class Encoder2
{
public:
	Encoder2(uint8_t pin1, uint8_t pin2) {
		#ifdef INPUT_PULLUP
		pinMode(pin1, INPUT_PULLUP);
		pinMode(pin2, INPUT_PULLUP);
		#else
		pinMode(pin1, INPUT);
		digitalWrite(pin1, HIGH);
		pinMode(pin2, INPUT);
		digitalWrite(pin2, HIGH);
		#endif
		encoder2.pin1_register = PIN_TO_BASEREG(pin1);
		encoder2.pin1_bitmask =  PIN_TO_BITMASK(pin1);
		encoder2.pin2_register = PIN_TO_BASEREG(pin2);
		encoder2.pin2_bitmask =  PIN_TO_BITMASK(pin2);
		encoder2.position = 0;
		// allow time for a passive R-C filter to charge
		// through the pullup resistors, before reading
		// the initial state
		delayMicroseconds(2000);
		uint8_t s = 0;
		if (DIRECT_PIN_READ(encoder2.pin1_register, encoder2.pin1_bitmask)) s |= 1;
		if (DIRECT_PIN_READ(encoder2.pin2_register, encoder2.pin2_bitmask)) s |= 2;
		encoder2.state = s;
		
#ifdef ENCODER_USE_INTERRUPTS
		interrupts_in_use = attach_interrupt(pin1, &encoder2);
		interrupts_in_use += attach_interrupt(pin2, &encoder2);
#endif
		//update_finishup();  // to force linker to include the code (does not work)
	}


#ifdef ENCODER_USE_INTERRUPTS
	inline int32_t read() {
		if (interrupts_in_use < 2) {
			noInterrupts();
			update(&encoder2);
		} else {
			noInterrupts();
		}
		int32_t ret = encoder2.position;
		interrupts();
		return ret;
	}
	inline int32_t readAndReset() {
		if (interrupts_in_use < 2) {
			noInterrupts();
			update(&encoder2);
		} else {
			noInterrupts();
		}
		int32_t ret = encoder2.position;
		encoder2.position = 0;
		interrupts();
		return ret;
	}
	inline void write(int32_t p) {
		noInterrupts();
		encoder2.position = p;
		interrupts();
	}
#else
	inline int32_t read() {
		update(&encoder2);
		return encoder2.position;
	}
	inline int32_t readAndReset() {
		update(&encoder2);
		int32_t ret = encoder2.position;
		encoder2.position = 0;
		return ret;
	}
	inline void write(int32_t p) {
		encoder2.position = p;
	}
#endif
private:
	Encoder_internal_state_t encoder2;
#ifdef ENCODER_USE_INTERRUPTS
	uint8_t interrupts_in_use;
#endif
public:
	static Encoder_internal_state_t * interruptArgs[ENCODER_ARGLIST_SIZE];

//                           _______         _______       
//               Pin1 ______|       |_______|       |______ Pin1
// negative <---         _______         _______         __      --> positive
//               Pin2 __|       |_______|       |_______|   Pin2

		//	new	new	old	old
		//	pin2	pin1	pin2	pin1	Result
		//	----	----	----	----	------
		//	0	0	0	0	no movement
		//	0	0	0	1	+1
		//	0	0	1	0	-1
		//	0	0	1	1	+2  (assume pin1 edges only)
		//	0	1	0	0	-1
		//	0	1	0	1	no movement
		//	0	1	1	0	-2  (assume pin1 edges only)
		//	0	1	1	1	+1
		//	1	0	0	0	+1
		//	1	0	0	1	-2  (assume pin1 edges only)
		//	1	0	1	0	no movement
		//	1	0	1	1	-1
		//	1	1	0	0	+2  (assume pin1 edges only)
		//	1	1	0	1	-1
		//	1	1	1	0	+1
		//	1	1	1	1	no movement
/*
	// Simple, easy-to-read "documentation" version :-)
	//
	void update(void) {
		uint8_t s = state & 3;
		if (digitalRead(pin1)) s |= 4;
		if (digitalRead(pin2)) s |= 8;
		switch (s) {
			case 0: case 5: case 10: case 15:
				break;
			case 1: case 7: case 8: case 14:
				position++; break;
			case 2: case 4: case 11: case 13:
				position--; break;
			case 3: case 12:
				position += 2; break;
			default:
				position -= 2; break;
		}
		state = (s >> 2);
	}
*/
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

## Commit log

2020-05-28 initial upload
    [DC-45PMBYR_ASS'Y.STEP, DC-45PMBYT_ASS'Y.STEP, HF-Sim-Ver2-BOM-1.xlsx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]
2020-05-29 Addition of Source code .9.18 5/29/2020 Teensy libraries
    [Throughput1 3D.xlsx]
2020-10-26 change structure of files
    change structure of files
    [DC-45PMBYR_ASS'Y.STEP, DC-45PMBYT_ASS'Y.STEP, HF-Sim-Ver2-BOM-1.xlsx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]
2020-10-27 updated files
    [HF-Sim-Ver2b-BOM.xlsx, Lafleur_DC-45PMBYT_ASS'Y v7.step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]
2020-11-02 added devices simulation files
    [Simulated performance October 24 2020 version 09_82.xlsx]
2020-11-04 Create Teensy IONOS HF Manual Rev 1.01.pdf
2020-11-30 Updated BOM
    [HF-Sim-Ver2b-BOM.xlsx, HF-Sim-Ver2b1-BOM.xlsx]
2025-07-29 added hardware files
    [PCB1.GBL, PCB1.GBO, PCB1.GBP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]
2025-07-31 added QEX Attachments
2026-03-17 Update readme new batch of boards.md
2026-07-26 added ver three board...
    [DC-45PMBYR_ASS'Y.STEP, DC-45PMBYT_ASS'Y.STEP, DC-45PMBYT_ASS'Y_BOX_Model v1.step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]
2026-07-28 added teensy 4.1 binary
2026-07-28 Update Teensy 4.1 binary
2026-07-29 Fix IONOS purchase link in README
    Updated the purchasing link for assembled IONOS and boards.
2026-07-29 Re order hardwarw
    [PCB1.GBL, PCB1.GBO, PCB1.GBP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]
2026-10-19 added schematic
2026-10-29 Fix BUSY command acknowledgements reporting ERROR after success
    A successful TONE ON or TONE OFF printed OK followed by
    "ACK BUSY/ENB BUSY:10 ... ERROR". BusyRequestConfirmed() requires
    intBusyMode to equal the requested item, but the serial BUSY dispatch
    never recorded the item it applied, so intBusyMode stayed at its reset
    value 0 (ENB BUSY). Every BUSY item other than ENB BUSY was affected,
    and the forced TFT refresh after each ACK redrew the ENB BUSY page over
    the page the setter had just drawn.
    The TONE setters also left the state the readback uses unchanged:
    TONE ON did not store intTestFreqHz or set blnEnableTestTone, TONE OFF
    did not clear the flag, and the DIS BUSY and TONE OFF rea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
2026-10-29 Add serial entry and exit for the TEST3K and TEST6K modes
    "TEST3K Sine:" and "TEST6K Sine:" answered "?" and left the simulator
    unchanged: ParseSimMode() stopped before the test modes, and compared
    the upper-cased command with the mixed-case table entries, so the front
    panel calibration modes could not be entered or verified remotely.
    Move the front panel entry for the two modes into ApplyTestMode() and
    the parameter-knob frequency setting into SetTestFrequency(), with the
    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
2026-11-06 Gate the periodic RMS report on DEBUG
    The loop prints a calibration report every 20,000 RMS updates even with
    DEBUG OFF. When the host is not reading the USB port (for example between
    commands from a controlling program), that unsolicited write can wait on an
    undrained transmit buffer and stall loop(). Print it only with DEBUG ON,
    like the other calibration diagnostics. Counters, RMS calculations, command
    replies, display and DSP settings are unchanged.
    Applied to both the main and the alternate-hardware sketches, with a source
    test that fails before and passes after.
